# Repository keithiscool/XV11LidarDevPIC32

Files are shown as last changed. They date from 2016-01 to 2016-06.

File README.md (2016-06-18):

This project uses the XV11 Lidar from a Neato Vacuum Cleaner to track a robot in an 4meter x 8meter arena
The object tracking uses the robot reflectance in order to only track reflective surfaces and objects that are far away from the walls
The MPLabX project "lidarpic_FloatingPoint.X" in the software folder uses a PIC32MX575F512H-80I/PT (ordered from Digikey) micro-controller running at 80MHz
The hardware PCB used is the "FAB_xv11_lidar_dev_2016_01_24" EagleCAD file located in the Hardware folder.

Note: you need to use an FTDI chip to debug the project.
Look at the 6 pin (looks like Arduino ISP header. 
FTDI board rx pin goes to Uart 6 on pic32
Ground goes to ground on the same 6 pin header

Next, run a serial debugger program on your pc like realterm, teraterm, arduino to debug the UART line from the pic32
Also double check the lidar is connected.
The headers are loose on the pic32 header for UART4. hook lidar brown/yellow wire (Lidar tx) to the pic32 (UART4RX). Hook up the lidar power and ground.

The MOSFET and Diode that are being pulsed use the circuit in the included PDF: "Lidar Development Using PIC32MX Microcontroller"
Next hook up the motor power to the +5V pin next to the air wired mosfet.
YOU WILL HAVE TO REPROGRAM THE pic32 when you first power it on with the pickit3 programmer. The pic32 will stop spinning the lidar until the pic32 is re-programmed.

I recommend you make the following changes for the Wii Camera/Lidar board.
1) Add 3.3V pin for Wii Cameras
2) Choose a pic32MX with more independent timers (1 or 2 more 16 bit timers) - the pic32 only has 4 independent timers
3) Switching buck converters (switching down power converters) to help with battery efficiency
4) Add more output capacitance for voltage LDO regulators if you do not use a switching regulator
5) Beef up 3.3V trace on board
6) Place 5V power for lidar next to lidar input pins (place +5V next to UA4RX)

7) Choose an isolated mosfet driver (the one we used was not isolated (grounds were tied – too much noise)
8) Integrate a large mosfet onto the board and use the mosfet driver with it with the attached circuit (see attachment)
9) Choosing locking connectors OR solder all wires to board
10) Move programming header closer to pic32 and avoid meandering traces under & over board

Recommendations:
11) Add a non-ultrasonic distance meter to help with backing up the robot
12) Get ultra-reflective surfaces for TRACEE to help with LIDAR (Aluminum reflectance varied too much from 70 to 130 quality)
13) Use a Gimbal/gyro on the Lidar to help keep it level with arena sand
14) Lower Lidar to sit in the arena like I left it (this will prevent false positives from the judges
15) Look into dust tolerance methods for Lidar (static electricity/magnetism/sound vibrations/solenoid)

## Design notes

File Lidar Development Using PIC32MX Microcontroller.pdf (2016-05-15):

## Neato XV11 Lidar Development Using PIC32MX Microcontroller

Keith Martin
NASA Robotics Mining Team

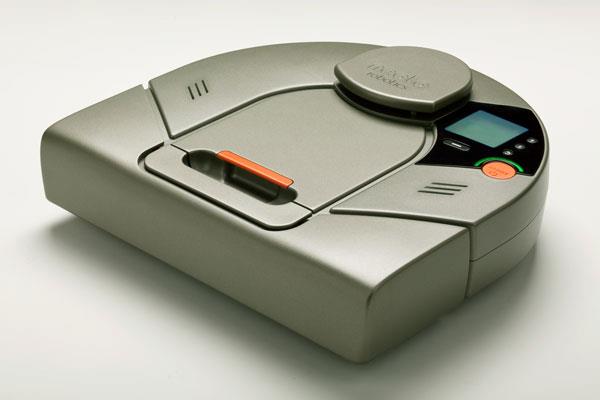
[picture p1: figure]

## CRC

- A Cyclical Redundancy Check is a method to verify that the received data is valid.
- The CRC used here is two bytes added on the end of the data message. The two bytes are compared with the received first bytes in green below.
<start> <index> <speed_L> <speed_H> [Data 0] [Data 1] [Data 2] [Data 3] <checksum_L> <checksum_H>

Parsed Output from Software After CRC

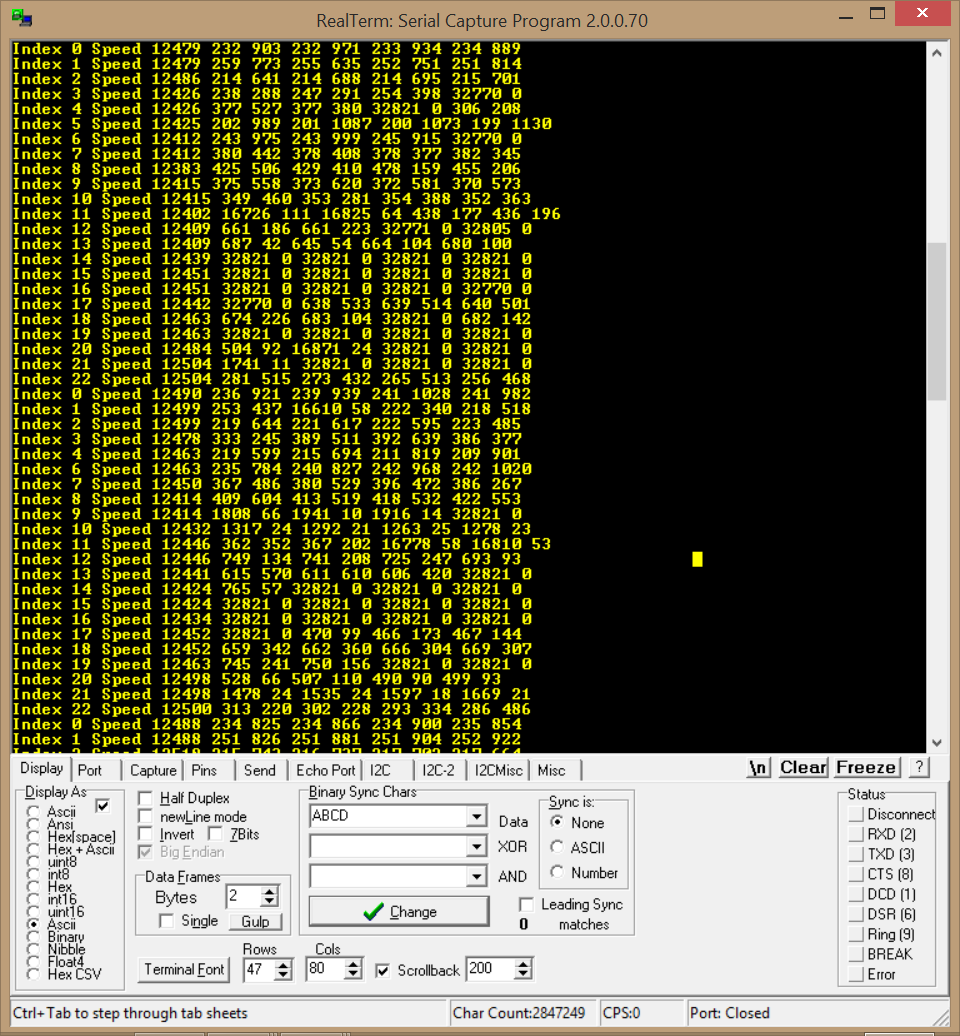
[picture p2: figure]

## How to Hookup the Lidar Hardware

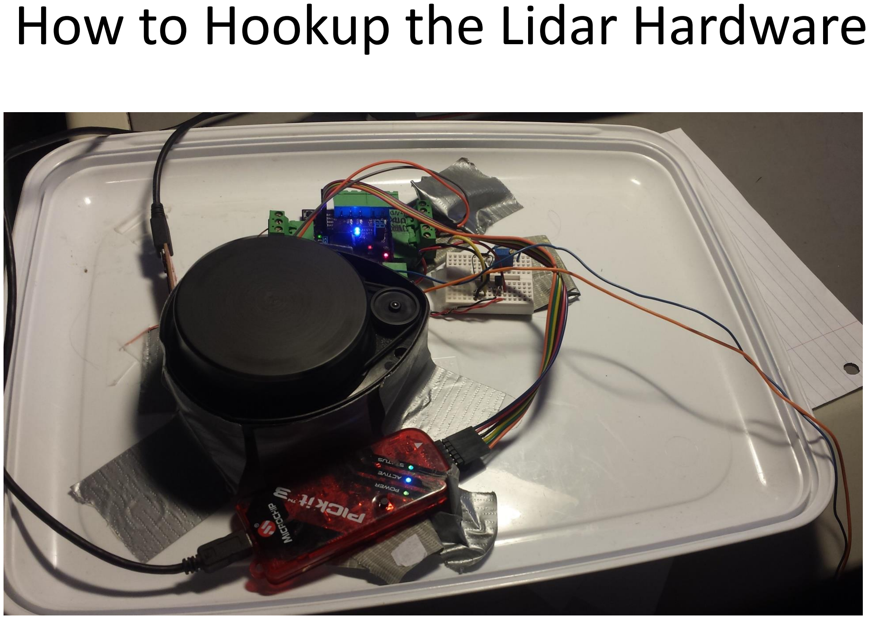
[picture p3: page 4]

## Fixed Point Math for Lookup Table

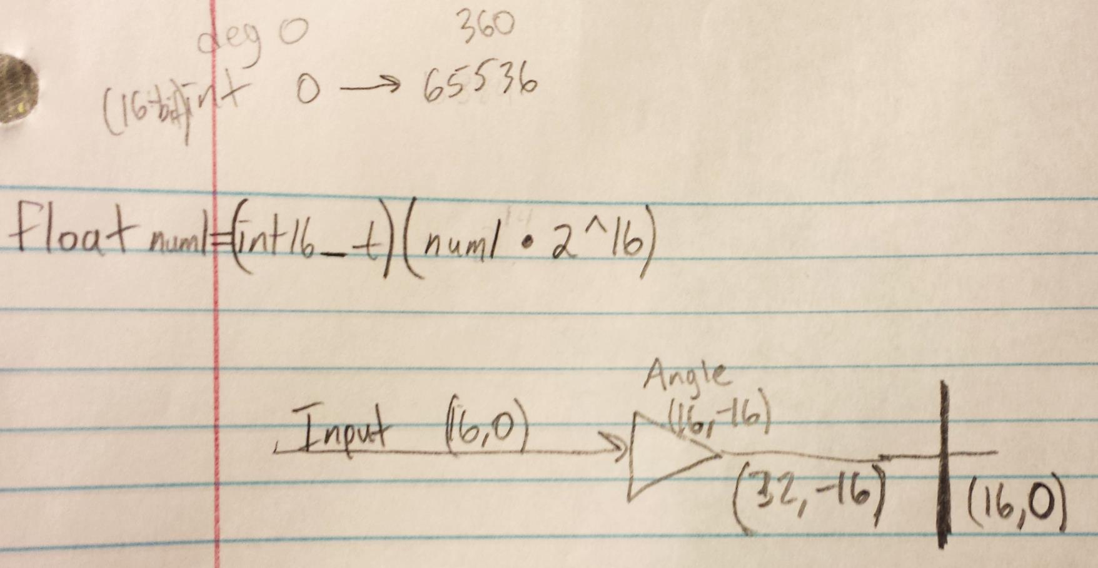
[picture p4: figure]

## Controlling the DC Motor

- Transistor base is connected to microcontroller
– Microcontroller sends PWM to transistor base – Diode prevents coils in
motor from inducing a large
voltage spike.

V = L

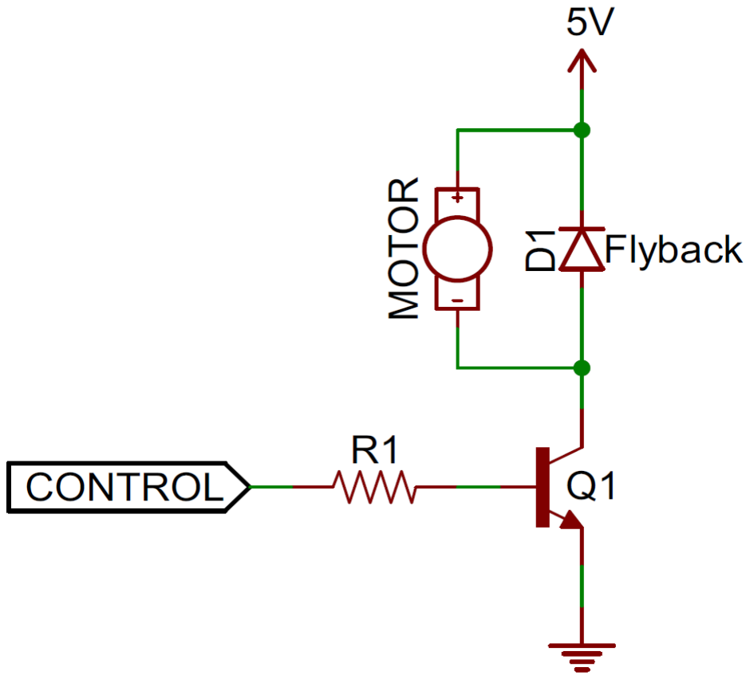
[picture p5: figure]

di
dt

## Site Info and Repository

https://xv11hacking.wikispaces.com/LIDAR+Senshttps://github.com/keithiscool/XV11LidarDevelopment PIC32 (https://github.com/keithiscool/XV11LidarDevelopmentPIC32)

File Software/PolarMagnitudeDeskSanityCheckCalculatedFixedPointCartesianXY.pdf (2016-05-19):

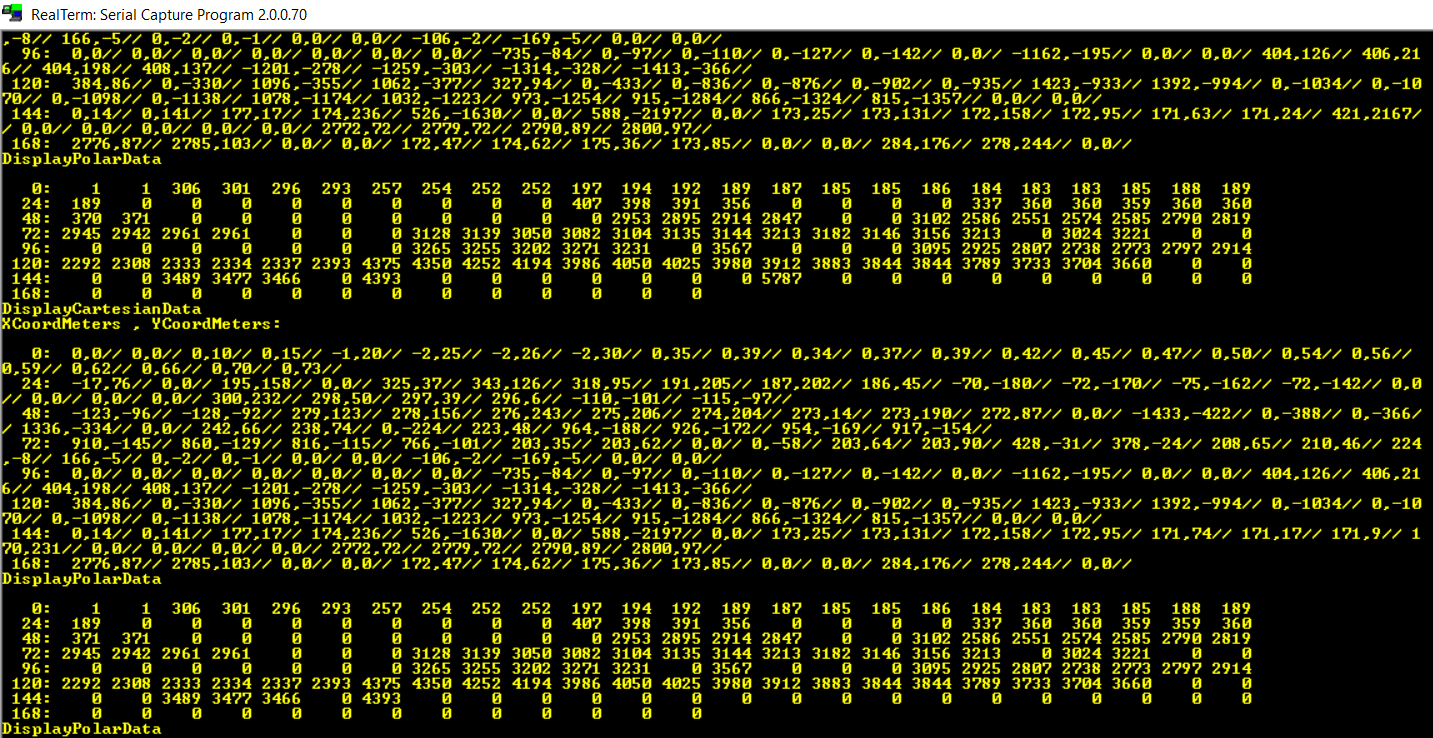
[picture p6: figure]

Lidar Polar Magnitudes on desk sanity check with the Calculated Fixed Point Cartesian X,Y coordinates

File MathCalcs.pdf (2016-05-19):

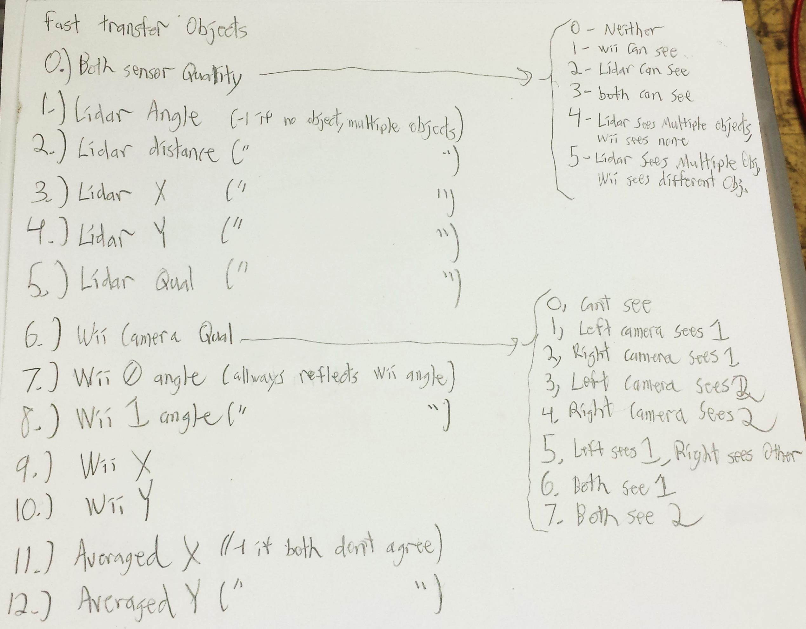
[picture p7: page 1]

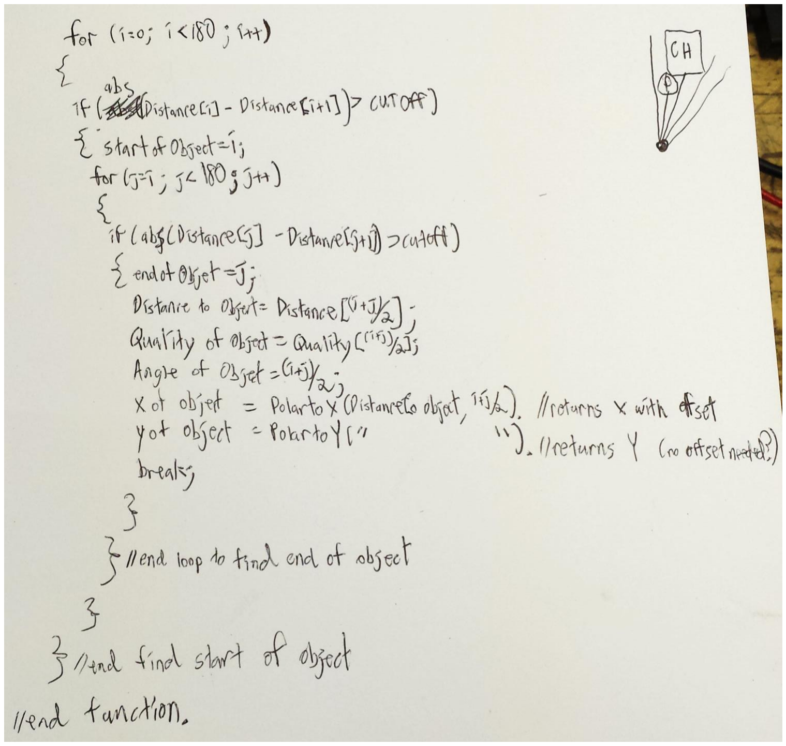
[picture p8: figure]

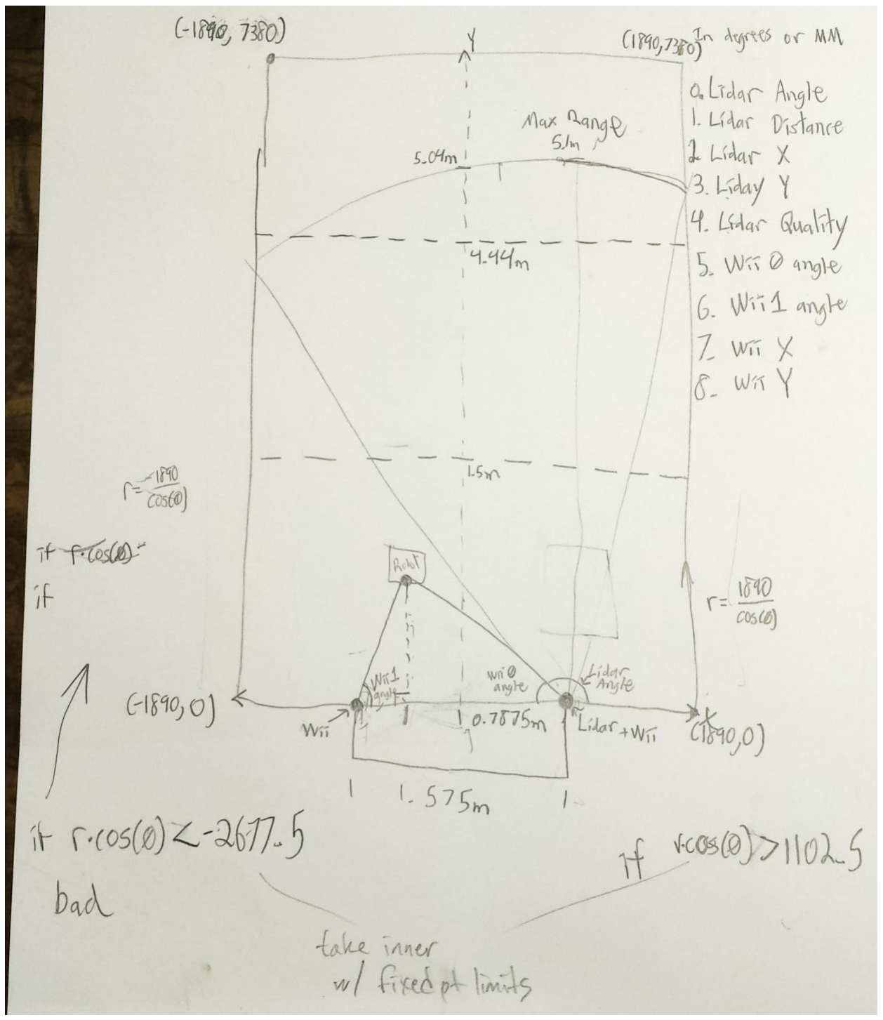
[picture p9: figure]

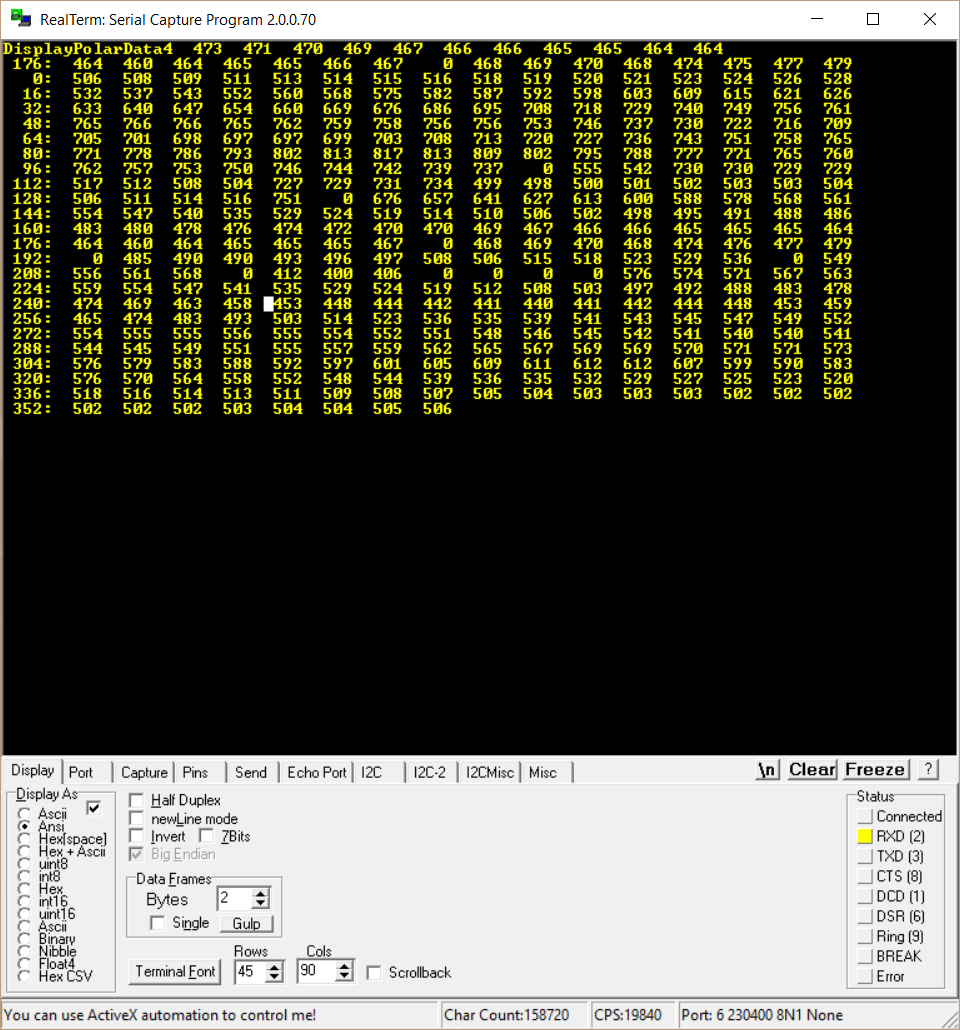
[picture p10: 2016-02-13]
Software/Data_Logging/XV11Lidar_Distances_Polar.png

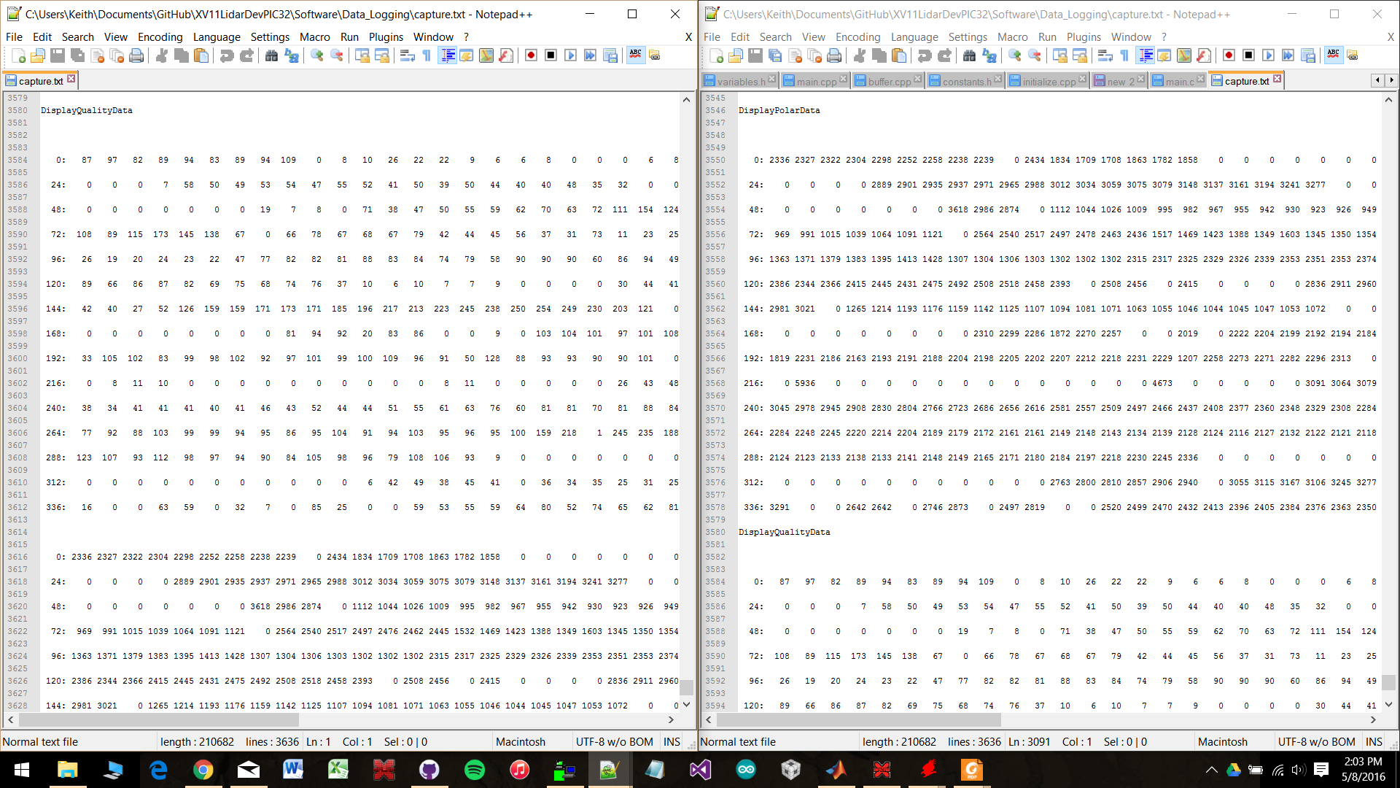
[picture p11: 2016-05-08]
Software/Data_Logging/QualityCheck.png

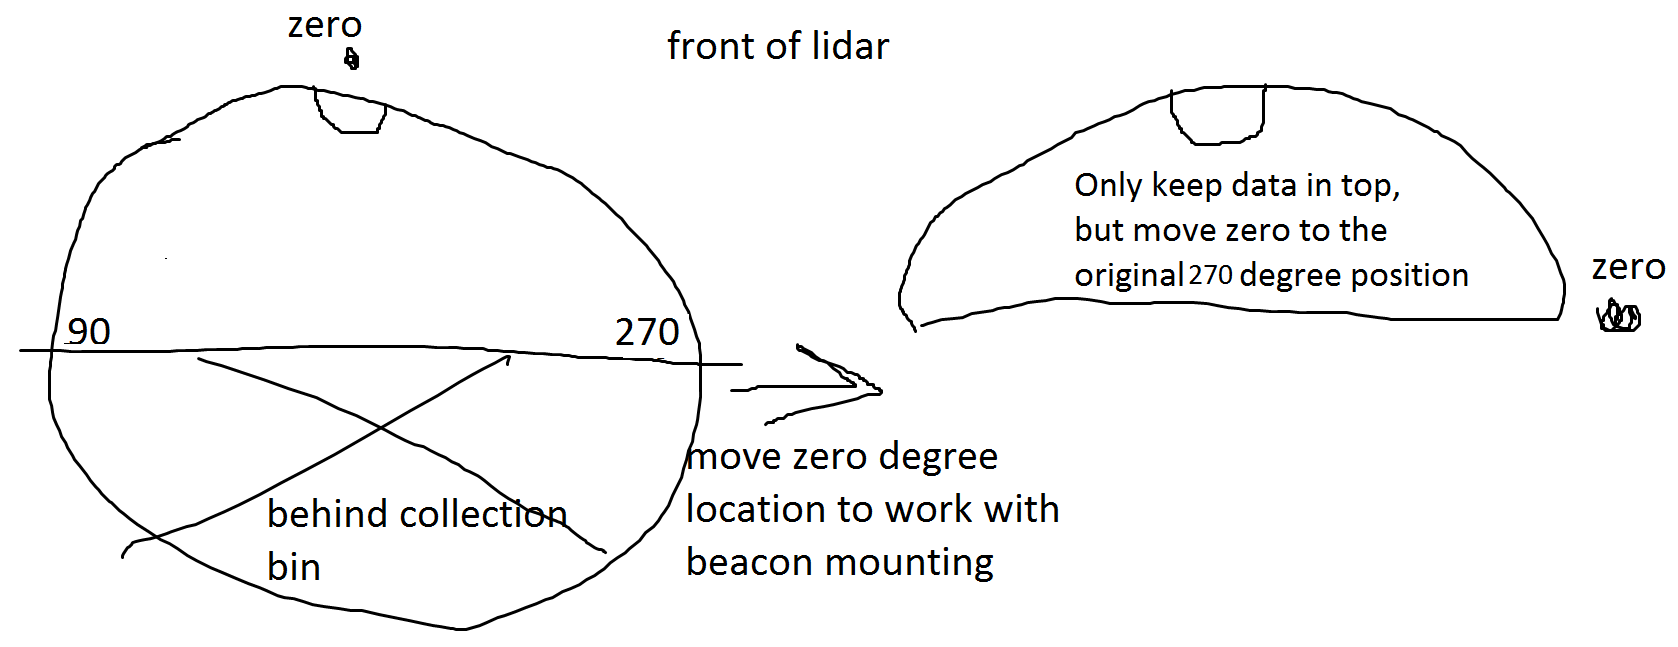
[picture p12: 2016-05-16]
Software/ReOrientLidarForBeaconAgainstCollectionWall.png

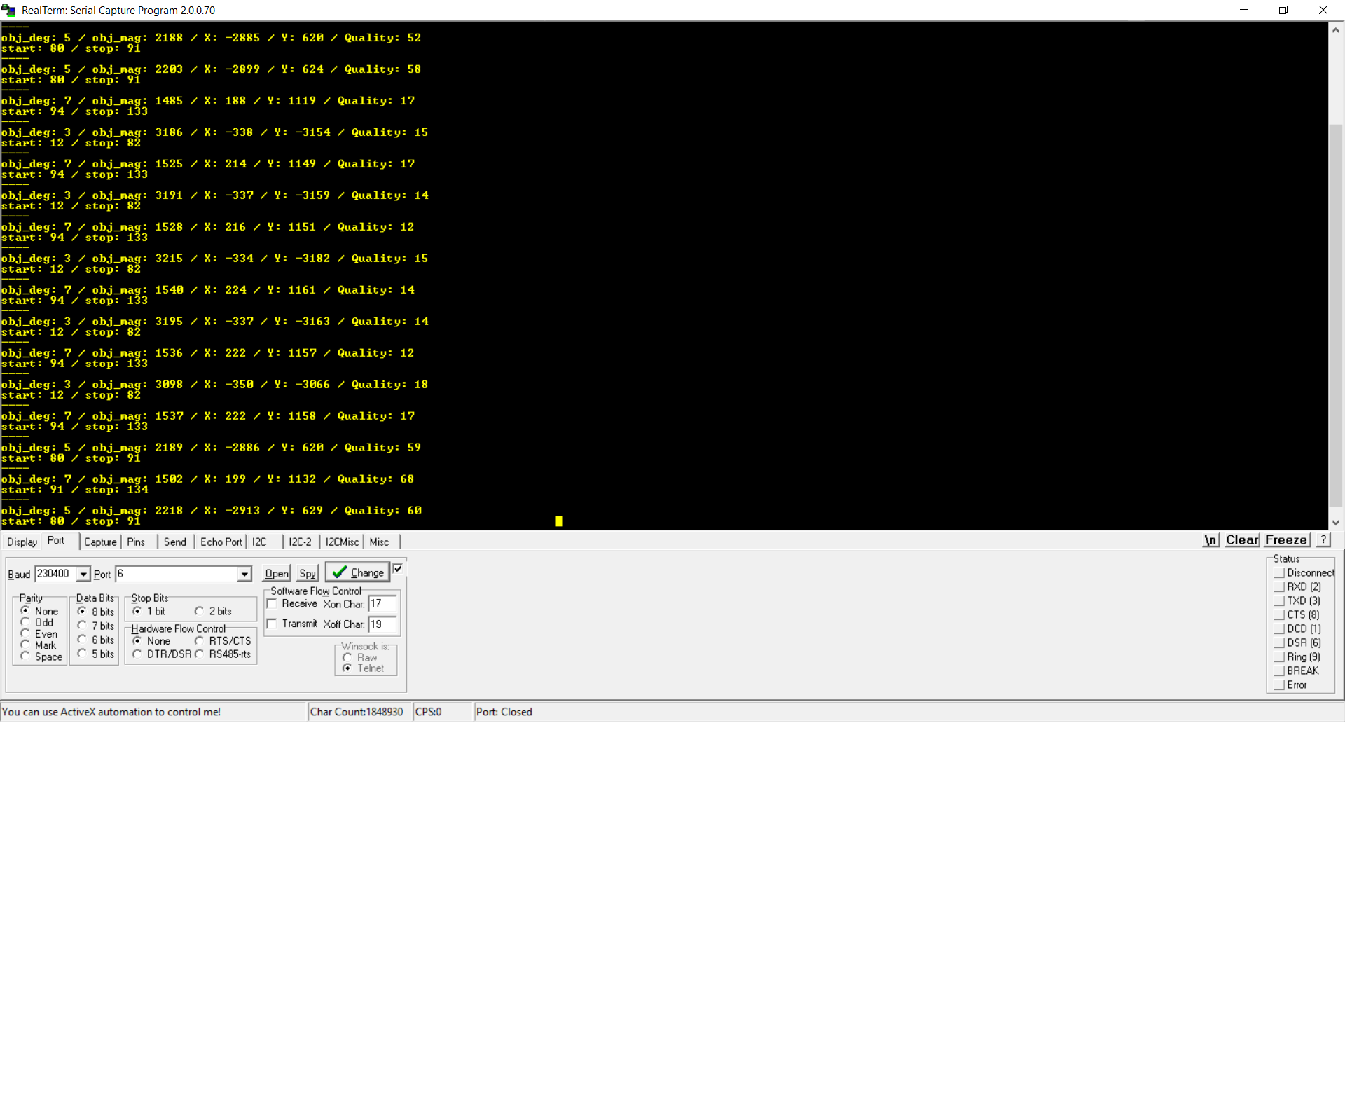
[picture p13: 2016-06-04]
Software/Data_Logging/WORKING_ObjectTrackingSample.png

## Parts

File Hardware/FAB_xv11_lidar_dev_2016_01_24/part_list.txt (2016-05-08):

Partlist

Exported from xv11_lidar_controller.brd at 4/28/2016 9:19:55 PM

EAGLE Version 6.5.0 Copyright (c) 1988-2013 CadSoft

Assembly variant: 

Part               Value                          Package                           Library                        Position (mil)        Orientation

3.3V_REG           BA33DD0WHFP-TR                 HRP5                              NASA_LIB                       (1240 2170)           MR0
ANALOG             M05LOCK                        1X05_LOCK                         SparkFun-Connectors            (1832.5 1012.5)       R90
C3                 1000pF Ceramic 50V             0805                              SparkFun-Capacitors            (1367.5 395)          MR90
C4                 0.1uF ceramic 16V              C0805K                            adafruit                       (755 1865)            MR270
C5                 100uf Tantalum 16v             EIA3216                           SparkFun-Capacitors            (555 1860)            MR90
C7                 10uF ceramic 16V               C0805K                            adafruit                       (672.5 1865)          MR270
C9                 10uf Ceramic 16v               0805                              SparkFun-Capacitors            (397.5 2200)          MR90
C12                0.1uF Ceramic                  0805                              SparkFun-Capacitors            (770 1410)            MR0
C13                0.1uF Ceramic                  0805                              SparkFun-Capacitors            (662.5 1305)          MR90
C14                0.1uF Ceramic                  0805                              SparkFun-Capacitors            (862.5 1307.5)        MR90
C15                0.1uF Ceramic                  0805                              SparkFun-Capacitors            (862.5 1190)          MR270
C16                0.1uF Ceramic                  0805                              SparkFun-Capacitors            (935 1600)            R0
C17                0.1uF Ceramic                  0805                              SparkFun-Capacitors            (447.5 1392.5)        R90
C18                0.1uF Ceramic                  0805                              SparkFun-Capacitors            (337.5 1147.5)        R90
C19                .1uF ceramic 50v               0805                              SparkFun-Capacitors            (1610 877.5)          MR0
C20                10uF Ceramic                   0805                              SparkFun-Capacitors            (712.5 1185)          MR270
C21                0.1uF Ceramic                  0805                              SparkFun-Capacitors            (795 1185)            MR270
C28                10uF ceramic 16V               0805                              SparkFun-Capacitors            (980 2130)            MR90
D1                 ES2AA-13-F                     SMA-DIODE                         SparkFun-DiscreteSemi          (405 1845)            MR90
D2                 ES2AA-13-F                     SMA-DIODE                         SparkFun-DiscreteSemi          (1270 272.5)          MR0
ECS-240-20-33-TR1  ECS-240-20-33-TR_24mHz_Digikey ECX-32                            Crystal ECS                    (320 1302.5)          R180
F1                 1AmpFuse_C1S 2                 R1206                             adafruit                       (1085 330)            MR90
F4                 4AmpFuse_C1S 2                 R1206                             adafruit                       (280 2570)            MR90
I2C1               M03LOCK                        1X03_LOCK                         SparkFun-Connectors            (947.5 2710)          R0
I2C2               M03LOCK                        1X03_LOCK                         SparkFun-Connectors            (595 2702.5)          R0
JP1                                               1X05_LOCK                         SparkFun-Connectors            (110 695)             R270
JP2                                               1X05_LOCK                         SparkFun-Connectors            (665 95)              R0
JP3                                               1X05_LOCK                         SparkFun-Connectors            (115 90)              R0
LED0               Blue                           CHIP-LED0805                      adafruit                       (1797.5 1972.5)       R90
LED1               Blue                           CHIP-LED0805                      adafruit                       (1797.5 2045)         R90
LED3               Blue                           CHIP-LED0805                      adafruit                       (1797.5 2112.5)       R90
LED4               Blue                           CHIP-LED0805                      adafruit                       (1795 2180)           R90
LED5               Blue                           CHIP-LED0805                      adafruit                       (1795 2247.5)         R90
LED6               Blue                           CHIP-LED0805                      adafruit                       (1787.5 1735)         R90
LED7               Blue                           CHIP-LED0805                      adafruit                       (1787.5 1840)         R90
LIDAR                                             1X04_LOCK                         SparkFun-Connectors            (1497.5 97.5)         R0
LIDAR_MOTOR_OUTPUT M02LOCK                        1X02_LOCK                         SparkFun-Connectors            (1220 97.5)           R0
MOTORA             Yellow                         CHIP-LED0805                      adafruit                       (810 455)             R180
PIC32              PIC32MX575F512H-80I/PT         QFP50P1200X1200X120-64N           Microchip_By_element14_Batch_1 (765 1285)            R180
PIC_PROG1          Prog                           1X05_LOCK_LONGPADS                SparkFun-Connectors            (1712.5 705)          R180
POWER              Green                          CHIP-LED0805                      adafruit                       (440 2720)            R270
Q1                 MOSFET-NCHANNELBSS138          SOT23                             SparkFun-DiscreteSemi          (990 1878)            MR0
Q2                 MOSFET-NCHANNELBSS138          SOT23                             SparkFun-DiscreteSemi          (1453 1817)           MR0
R1                 10 5%                          R0805                             adafruit                       (1085 1605)           R0
R2                 2.2k                           R0805                             adafruit                       (1285 1940)           R270
R3                 10k 5%                         R0805                             adafruit                       (1499 2358)           MR270
R4                 100 5%                         M0805                             adafruit                       (772.5 327.5)         R0
R5                 100 5%                         R0805                             adafruit                       (951 1734)            MR0
R6                 2.2k                           R0805                             adafruit                       (1787.5 1617.5)       MR0
R7                 100 5%                         R0805                             adafruit                       (1170 1000)           R90
R8                 2.2k                           M0805                             adafruit                       (640 495)             R180
R9                 10k 5%                         R0805                             adafruit                       (1460 955)            R270
R10                2.2k                           R0805                             adafruit                       (1365 1940)           R270
R11                2.2k                           R0805                             adafruit                       (1205 1940)           R270
R12                2.2k                           R0805                             adafruit                       (1125 1940)           R270
R13                2.2k                           R0805                             adafruit                       (1045 1940)           R270
R14                2.2k                           R0805                             adafruit                       (1787.5 1732.5)       MR0
R15                2.2k                           R0805                             adafruit                       (1787.5 1837.5)       MR0
R16                2.2k 5%                        R0805                             adafruit                       (869 1866)            MR270
R17                2.2k 5%                        R0805                             adafruit                       (1343 1713)           MR270
R18                2.2k 5%                        M0805                             adafruit                       (1810 262.5)          R0
R19                2.2k 5%                        M0805                             adafruit                       (1455 267.5)          R180
R20                100 5%                         R0805                             adafruit                       (1700 1285)           MR180
R21                100 5%                         R0805                             adafruit                       (1468 1669)           MR0
R22                10k 5%                         R0805                             adafruit                       (1712 2366)           MR270
R23                100 5%                         R0805                             adafruit                       (1700 1205)           MR180
R24                100 5%                         R0805                             adafruit                       (1700 1125)           MR180
R25                100 5%                         R0805                             adafruit                       (1700 1045)           MR180
R26                100 5%                         R0805                             adafruit                       (1700 1365)           MR180
R39                2.2k                           R0805                             adafruit                       (397.5 2360)          MR90
S1                                                TACTILE-SWITCH-SMD                SparkFun-Electromechanical     (815 705)             R180
SERVO1                                            1X03                              SparkFun-Connectors            (1492.5 2712.5)       R180
SERVO2                                            1X03                              SparkFun-Connectors            (1840 2715)           R180
TOUCHSCREEN                                       2X3-NS                            SparkFun-Connectors            (1610 432.5)          R0
U$1                ULN2003                        SOIC16_3.9WIDE                    NASA_LIB                       (810 485)             MR180
U$2                ULN2003                        SOIC16_3.9WIDE                    NASA_LIB                       (355 540)             MR270
U$3                JUMPER-PAD-2-NC_BY_TRACE       PAD-JUMPER-2-NC_BY_TRACE_YES_SILK SparkFun-Passives              (287.5 1562.5)        R0
U$4                JUMPER-PAD-2-NC_BY_TRACE       PAD-JUMPER-2-NC_BY_TRACE_YES_SILK SparkFun-Passives              (287.5 1504)          R0
U$5                JUMPER-PAD-2-NC_BY_TRACE       PAD-JUMPER-2-NC_BY_TRACE_YES_SILK SparkFun-Passives              (360.5 1854.5)        R90
U$6                JUMPER-PAD-2-NC_BY_TRACE       PAD-JUMPER-2-NC_BY_TRACE_YES_SILK SparkFun-Passives              (301.5 1855)          R90
U1                 BA50DD0WHFP-TR                 HRP5                              NASA_LIB                       (690 2170)            MR0
U2                 LANTRONIX_A/B                  LANA/BTH                          NASA_LIB                       (885 1745)            R0
U3                 MIC4427YM                      SO-08                             transistor-power               (1167.5 355)          R0
UARTRX4            Green                          CHIP-LED0805                      adafruit                       (1695 232.5)          R180
UARTTX4            Red                            CHIP-LED0805                      adafruit                       (1592.5 232.5)        R180
VIN                M02LOCK                        1X02_LOCK                         SparkFun-Connectors            (165 2750)            R0
WLAN               Blue                           CHIP-LED0805                      adafruit                       (1787.5 1617.5)       R90

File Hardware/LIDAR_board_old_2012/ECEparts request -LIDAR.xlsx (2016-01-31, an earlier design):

 |  |  | ECE PARTS REQUEST ORDERING FORM
 |  | Student Name: | Richard Johnson | Email:
 |  | Project Name: | NASA Lunabot |  | Date Submitted:
 | Faculty Advisor Approval: |  |  |  | Date Ordered:
 |  | Email the completed form to: | glewis@uakron.edu |  | Ordered By:
 |  |  |  |  |  |  | Unit | Total
Qty. | Refdes | Part Num. | Description | Suggested Vendor | Vendor Part Num. | Catalog #/Page #/Website | Cost | Cost
4 |  | 440054-4 | CONN HEADER 4POS 2MM VERT | Digikey | A100036-ND | http://search.digikey.com/us/en/products/440054-4/A100036-ND/2077941?wt.mc_id=Dxn_US_US2010_Catlink | 0.28 | 1.12
4 |  | 440054-2 | CONN HEADER 2POS 2MM VERT | Digikey | A100034-ND | http://search.digikey.com/us/en/products/440054-2/A100034-ND/2077939?wt.mc_id=Dxn_US_US2010_Catlink | 0.11 | 0.44
4 |  | ATMEGA644P-20AU | IC MCU AVR 64K FLASH 44-TQFP | Digikey | ATMEGA644P-20AU-ND | http://search.digikey.com/us/en/products/ATMEGA644P-20AU/ATMEGA644P-20AU-ND/1245864 | 8.08 | 32.32
8 |  | T491A106M016AT | CAP TANT 10UF 16V | Digikey | 399-3687-1-ND | http://search.digikey.com/us/en/products/T491A106M016AT/399-3687-1-ND/819012 | 0.54 | 4.32
4 |  | T491C106K025AT | CAP TANT 10UF 25V | Digikey | 399-3734-1-ND | http://search.digikey.com/us/en/products/T491C106K025AT/399-3734-1-ND/819059 | 0.79 | 3.16
4 |  | 0ZCA0020FF2E | PTC RESTTBLE 0.20A 30V | Digikey | 507-1478-1-ND | http://search.digikey.com/us/en/products/0ZCA0020FF2E/507-1478-1-ND/2165307 | 0.28 | 1.12
20 |  | GRM21BR71E104KA01L | CAP CER 0.1UF 25V | Digikey | 490-1673-1-ND | http://search.digikey.com/us/en/products/GRM21BR71E104KA01L/490-1673-1-ND/587412 | 0.188 | 3.76
12 |  | ERJ-6GEYJ102V | RES 1.0K OHM 1/8W | Digikey | P1.0KACT-ND | http://search.digikey.com/us/en/products/ERJ-6GEYJ102V/P1.0KACT-ND/42833 | 0.04 | 0.48
4 |  | ERJ-6GEYJ103V | RES 10K OHM 1/8W | Digikey | P10KACT-ND | http://search.digikey.com/us/en/products/ERJ-6GEYJ103V/P10KACT-ND/43118 | 0.04 | 0.16
4 |  | LTST-C191KGKT | LED GREEN CLEAR THIN 0603 SMD | Digikey | 160-1446-1-ND | http://search.digikey.com/us/en/products/LTST-C191KGKT/160-1446-1-ND/386834 | 0.45 | 1.80
4 |  | LTST-C190KRKT | LED SUPER RED CLEAR 0603 | Digikey | 160-1436-1-ND | http://search.digikey.com/us/en/products/LTST-C190KRKT/160-1436-1-ND/386816 | 0.41 | 1.64
4 |  | LTST-C190KYKT | LED AMBER YELLOW CLEAR 0603 | Digikey | 160-1438-1-ND | http://search.digikey.com/us/en/products/LTST-C190KYKT/160-1438-1-ND/386820 | 0.46 | 1.84
4 |  | MAX485CSA+ | IC TXRX RS485/RS422 LOWPWR 8SOIC | Digikey | MAX485CSA+-ND | http://search.digikey.com/us/en/products/MAX485CSA%2B/MAX485CSA%2B-ND/948027 | 2.89 | 11.56
4 |  | EVQ-PF008K | SWITCH TACTILE SPST-NO | Digikey | P10880S-ND | http://search.digikey.com/scripts/DkSearch/dksus.dll?WT.z_header=search_go&lang=en&site=us&x=0&y=0 | 0.29 | 1.16
20 |  | 1547E | STANDOFF RND 4-40THR BR 1.00"L | Digikey | 1547EK-ND | http://search.digikey.com/us/en/products/1547E/1547EK-ND/303619 | 1.197 | 23.94
1 |  | uLCD43 | Serial TFT LCD 4.3" with Touchscreen | Sparkfun | LCD-11075 | http://www.sparkfun.com/products/11075 | 139.95 | 139.95
4 |  | BlinkM MaxM | I2C Controlled RGB LED | Sparkfun | COM-09000 | http://www.sparkfun.com/products/9000 | 24.95 | 99.80
1 |  | N/A | Metal Pushbutton with Red LED Ring -NO | Adafruit | 559 | https://www.adafruit.com/products/559 | 5.95 | 5.95
 |  |  |  |  |  |  |  | 0.00
 |  |  |  |  |  |  |  | 0.00
 |  |  |  |  |  |  |  | 0.00
 |  |  |  |  |  |  |  | 0.00
 |  |  |  |  |  |  |  | 0.00
 |  |  |  |  |  |  |  | 0.00
 |  |  |  |  |  |  |  | 0.00
 |  |  |  |  |  |  |  | 0.00
 |  |  |  |  |  |  |  | 0.00
 |  |  |  |  |  |  |  | 0.00
 |  |  |  |  |  |  |  | 0.00
 |  |  |  |  |  |  |  | 0.00
 |  |  |  |  |  |  |  | 0.00
 |  |  |  |  |  |  |  | 0.00
 |  |  |  |  |  |  |  | 0.00
 |  |  |  |  |  |  |  | 0.00
 |  |  |  |  |  |  |  | 0.00
 |  |  |  |  |  |  |  | 0.00
 |  |  |  |  |  |  |  | 0.00
 |  |  |  |  |  |  |  | 0.00
 |  |  |  |  |  |  |  | 0.00
 |  |  |  |  |  |  |  | 0.00
 |  |  |  |  |  |  | Total | $334.52

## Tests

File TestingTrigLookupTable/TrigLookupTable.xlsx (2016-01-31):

 | Fixed Point Math: |  | http://stackoverflow.com/questions/187713/converting-floating-point-to-fixed-point
 | DO NOT EXCEED: |  | 4294967296 |  | 65536 | Scaled to 16 bits | Output in (16,-16) Format == 0integer bits,16fraction bits
 | Scaler: | 1000
Degrees | SinVal(float) | round(SinVal(float)*Scaler) |  | Scaled Int Value = float*2^16 |  | Rounded Int Value
0 | 0 | 0 |  | 0 |  | 0
1 | 0.01745240644 | 17 |  | 1143.760908 |  | 1144
2 | 0.0348994967 | 35 |  | 2287.173416 |  | 2287
3 | 0.05233595624 | 52 |  | 3429.889228 |  | 3430
4 | 0.06975647374 | 70 |  | 4571.560263 |  | 4572
5 | 0.08715574275 | 87 |  | 5711.838757 |  | 5712
6 | 0.1045284633 | 105 |  | 6850.377369 |  | 6850
7 | 0.1218693434 | 122 |  | 7986.829289 |  | 7987
8 | 0.139173101 | 139 |  | 9120.848345 |  | 9121
9 | 0.156434465 | 156 |  | 10252.0891 |  | 10252
10 | 0.1736481777 | 174 |  | 11380.20697 |  | 11380
11 | 0.1908089954 | 191 |  | 12504.85832 |  | 12505
12 | 0.2079116908 | 208 |  | 13625.70057 |  | 13626
13 | 0.2249510543 | 225 |  | 14742.3923 |  | 14742
14 | 0.2419218956 | 242 |  | 15854.59335 |  | 15855
15 | 0.2588190451 | 259 |  | 16961.96494 |  | 16962
16 | 0.2756373558 | 276 |  | 18064.16975 |  | 18064
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

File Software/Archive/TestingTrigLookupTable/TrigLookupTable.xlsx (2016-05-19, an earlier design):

 | Fixed Point Math: |  | http://stackoverflow.com/questions/187713/converting-floating-point-to-fixed-point
 | DO NOT EXCEED: | Size of int_32_unsigned: 2147483648 |  |  | 65536 | Scaled to 16 bits | Output in (16,-16) Format == 0integer bits,16fraction bits
 | Scaler: | 1000
Degrees | SinVal(float) | round(SinVal(float)*Scaler) |  | Scaled Int Value = float*2^16 |  | Rounded Int Value
0 | 0 | 0 |  | 0 |  | 0
1 | 0.01745240644 | 17 |  | 1143.760908 |  | 1144
2 | 0.0348994967 | 35 |  | 2287.173416 |  | 2287
3 | 0.05233595624 | 52 |  | 3429.889228 |  | 3430
4 | 0.06975647374 | 70 |  | 4571.560263 |  | 4572
5 | 0.08715574275 | 87 |  | 5711.838757 |  | 5712
6 | 0.1045284633 | 105 |  | 6850.377369 |  | 6850
7 | 0.1218693434 | 122 |  | 7986.829289 |  | 7987
8 | 0.139173101 | 139 |  | 9120.848345 |  | 9121
9 | 0.156434465 | 156 |  | 10252.0891 |  | 10252
10 | 0.1736481777 | 174 |  | 11380.20697 |  | 11380
11 | 0.1908089954 | 191 |  | 12504.85832 |  | 12505
12 | 0.2079116908 | 208 |  | 13625.70057 |  | 13626
13 | 0.2249510543 | 225 |  | 14742.3923 |  | 14742
14 | 0.2419218956 | 242 |  | 15854.59335 |  | 15855
15 | 0.2588190451 | 259 |  | 16961.96494 |  | 16962
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

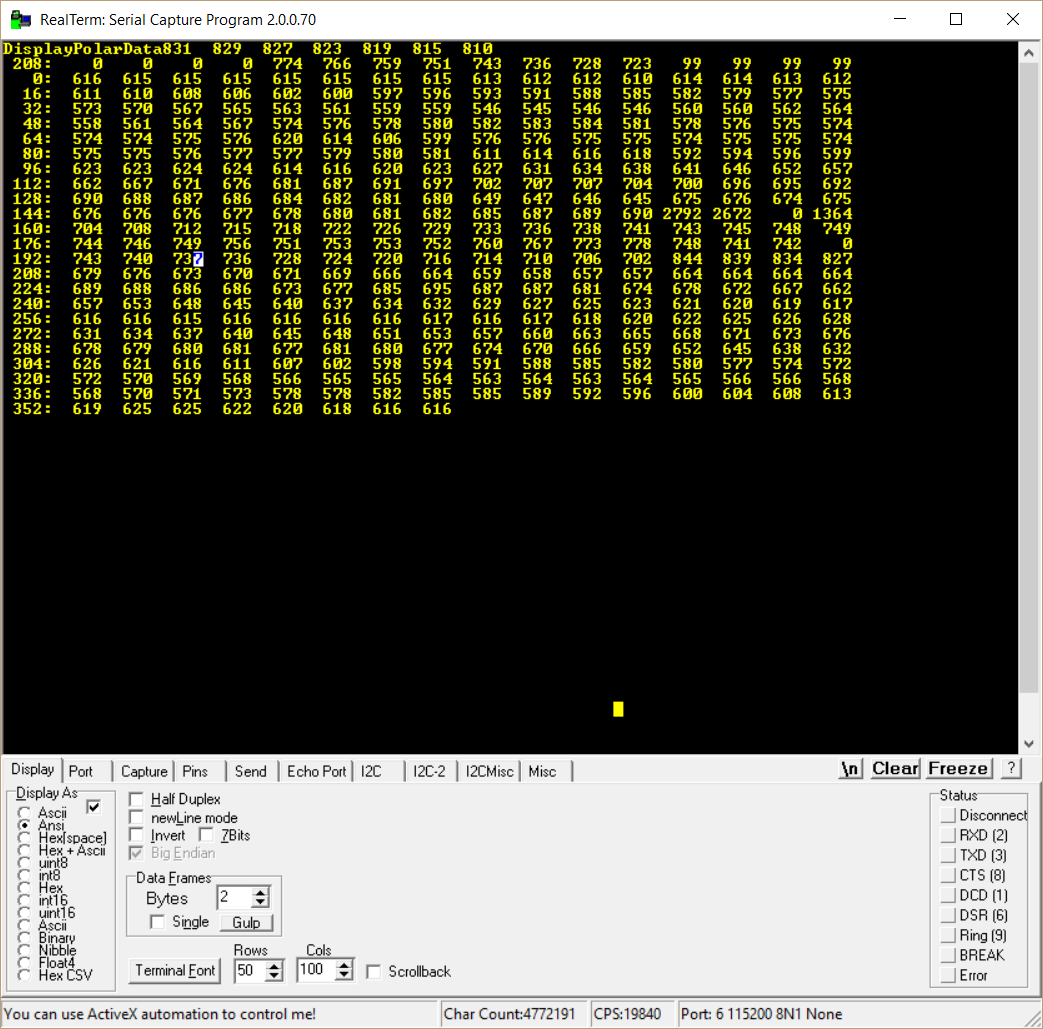
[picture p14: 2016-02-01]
Software/Data_Logging/CircleTestXV11_50cmRadiusCircleWhiteCardboard.png

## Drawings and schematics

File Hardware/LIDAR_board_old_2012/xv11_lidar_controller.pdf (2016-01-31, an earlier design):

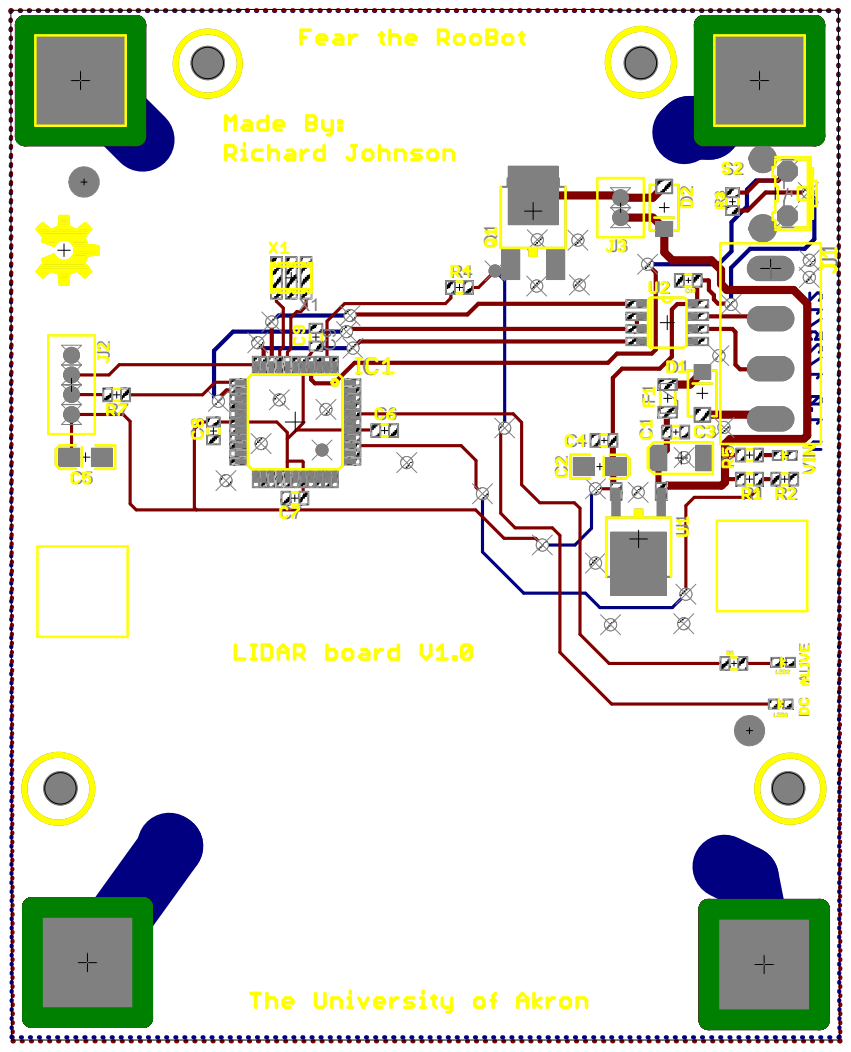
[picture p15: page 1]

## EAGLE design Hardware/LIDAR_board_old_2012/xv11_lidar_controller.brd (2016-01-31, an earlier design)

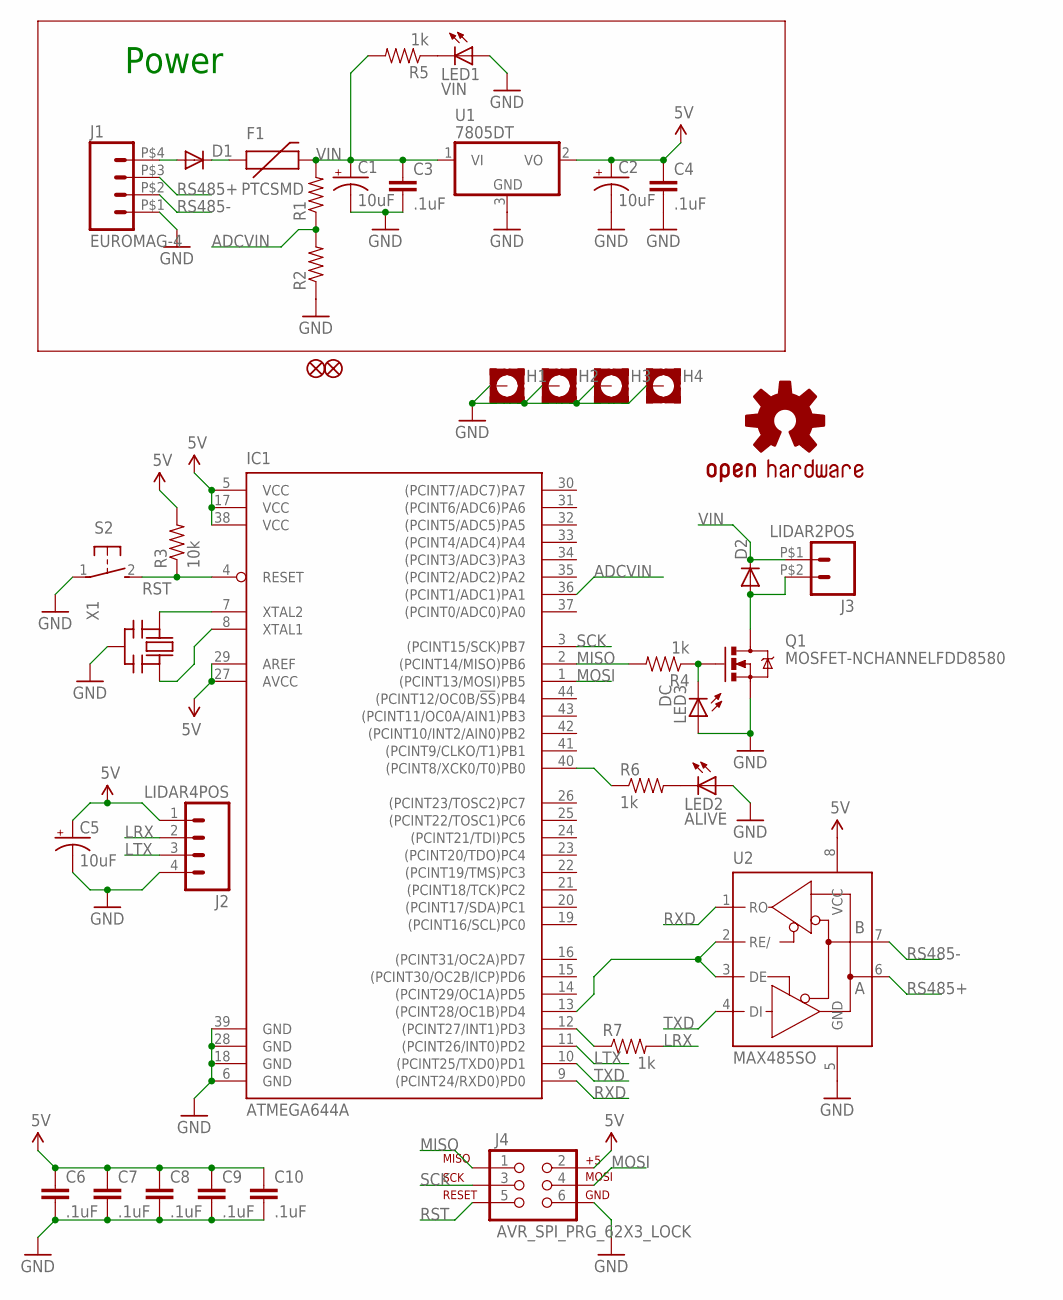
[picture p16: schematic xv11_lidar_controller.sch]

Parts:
C1: 10uF; EIA6032
C2, C5: 10uF; EIA3216-KIT
C3, C4, C6, C7, C8, C9, C10: .1uF; 0805
D1, D2: DIODESMA; SMA-DIODE
F1: PTCSMD; PTC-1206
H1, H2, H3, H4: MOUNT-PAD-SQUARE5.5; 5,5-PAD-SQUARE
IC1: ATMEGA644A; TQFP44
J1: EUROMAG-4; M4
J2: LIDAR4POS; 2MM4POS
J3: LIDAR2POS; 2MM2POS
J4: AVR_SPI_PRG_62X3_LOCK; 2X3_LOCK
JP1, JP2: FIDUCIAL1.5X3; FIDUCIAL-1.5X3
LED1: VIN; LED-0603
LED2: ALIVE; LED-0603
LED3: DC; LED-0603
Q1: MOSFET-NCHANNELFDD8580; DPAK
R1, R2: RESISTOR0805-RES; 0805
R3: 10k; 0805
R4, R5, R6, R7: 1k; 0805
S2: 31-XX; B3F-31XX
U1: 7805DT; TO252
U2: MAX485SO; SO08
U$2: OSHW-LOGOL; OSHW-LOGO-L
X1: CERMOSCILL-AWCSR; AWCSR

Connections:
5V: C2.A (+), C4.1, C5.A (+), C6.1, C7.1, C8.1, C9.1, C10.1, IC1.5 (VCC), IC1.17 (VCC), IC1.27 (AVCC), IC1.29 (AREF), IC1.38 (VCC), J2.1, J4.2, R3.2, U1.2 (VO), U2.8 (VCC)
ADCVIN: IC1.36 ((PCINT1/ADC1)PA1), R1.1, R2.2
GND: C1.P$2 (-), C2.C (-), C3.2, C4.2, C5.C (-), C6.2, C7.2, C8.2, C9.2, C10.2, H1.B5,5, H2.B5,5, H3.B5,5, H4.B5,5, IC1.6 (GND), IC1.18 (GND), IC1.28 (GND), IC1.39 (GND), J1.P$1 (1), J2.4, J4.6, LED1.A, LED2.A, LED3.A, Q1.3 (S), R2.1, S2.1, U1.3 (GND), U2.5 (GND), X1.2 (GND)
LRX: J2.2, R7.2
LTX: IC1.11 ((PCINT26/INT0)PD2), J2.3
MISO: IC1.2 ((PCINT14/MISO)PB6), J4.1, R4.2
MOSI: IC1.1 ((PCINT13/MOSI)PB5), J4.4
unnamed: D1.A, J1.P$4 (4)
unnamed: D1.C, F1.1
unnamed: LED3.C, Q1.1 (G), R4.1
unnamed: LED1.C, R5.1
unnamed: IC1.40 ((PCINT8/XCK0/T0)PB0), R6.1
unnamed: LED2.C, R6.2
unnamed: D2.A, J3.P$2 (2), Q1.4 (D)
unnamed: IC1.13 ((PCINT28/OC1B)PD4), U2.2 (RE/), U2.3 (DE)
unnamed: IC1.12 ((PCINT27/INT1)PD3), R7.1
unnamed: IC1.7 (XTAL2), X1.1 (IN)
unnamed: IC1.8 (XTAL1), X1.3 (OUT)
RS485+: J1.P$3 (3), U2.6 (A)
RS485-: J1.P$2 (2), U2.7 (B)
RST: IC1.4 (RESET), J4.5, R3.1, S2.2 (S)
RXD: IC1.9 ((PCINT24/RXD0)PD0), U2.1 (RO)
SCK: IC1.3 ((PCINT15/SCK)PB7), J4.3
TXD: IC1.10 ((PCINT25/TXD0)PD1), U2.4 (DI)
VIN: C1.P$1 (+), C3.1, D2.C, F1.2, J3.P$1 (1), R1.2, R5.2, U1.1 (VI)

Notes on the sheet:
Power

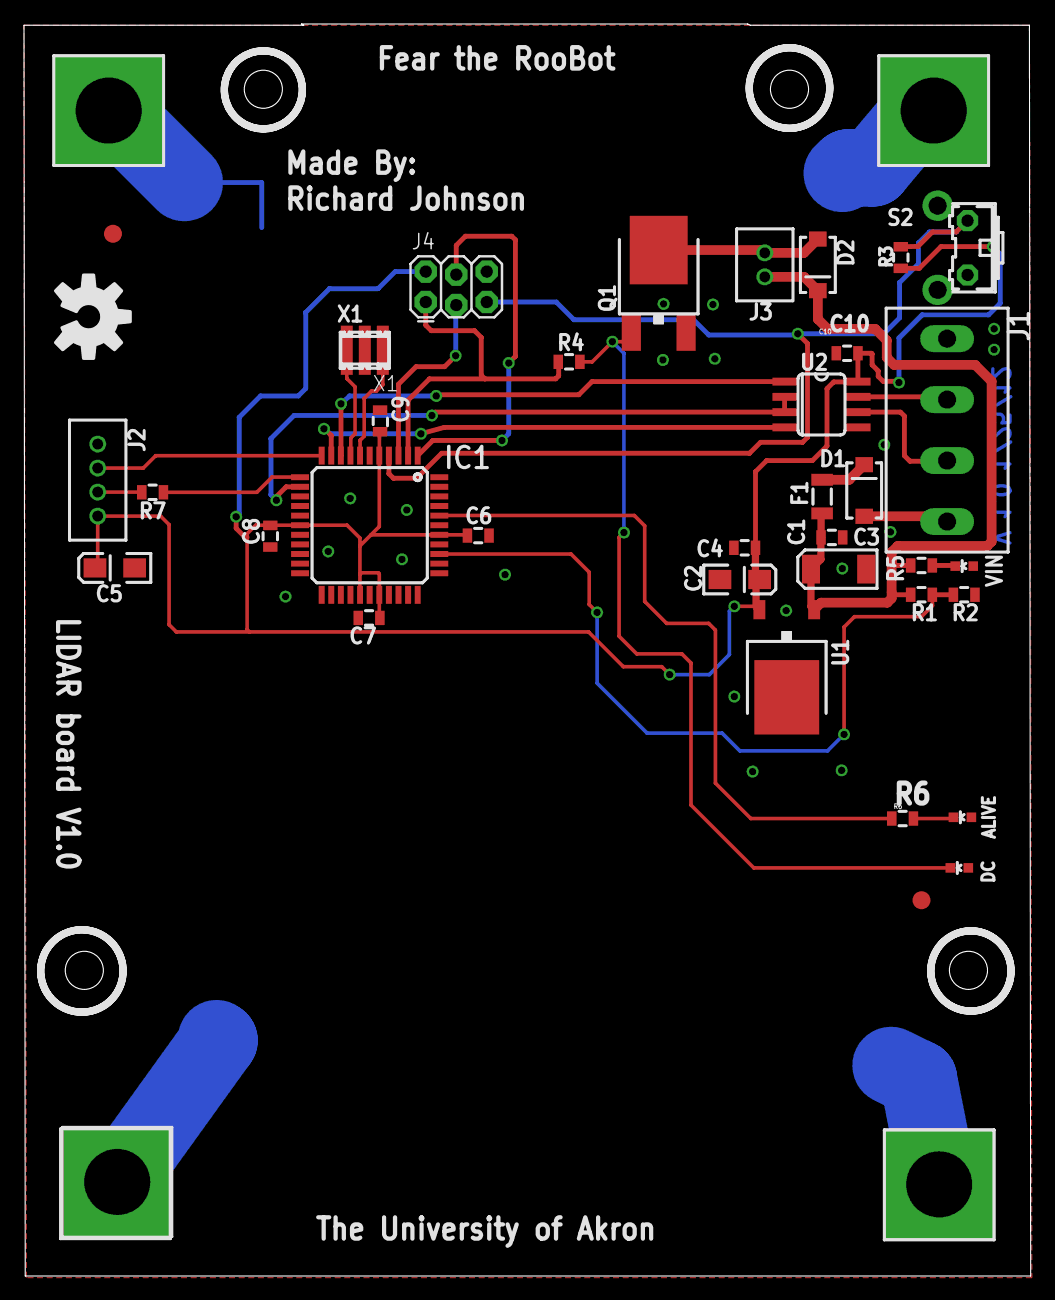
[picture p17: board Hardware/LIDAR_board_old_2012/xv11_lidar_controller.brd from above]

Board: 2 copper layers, 83.9 x 104.3 mm, 40 parts (0 on the bottom side), 25 nets.

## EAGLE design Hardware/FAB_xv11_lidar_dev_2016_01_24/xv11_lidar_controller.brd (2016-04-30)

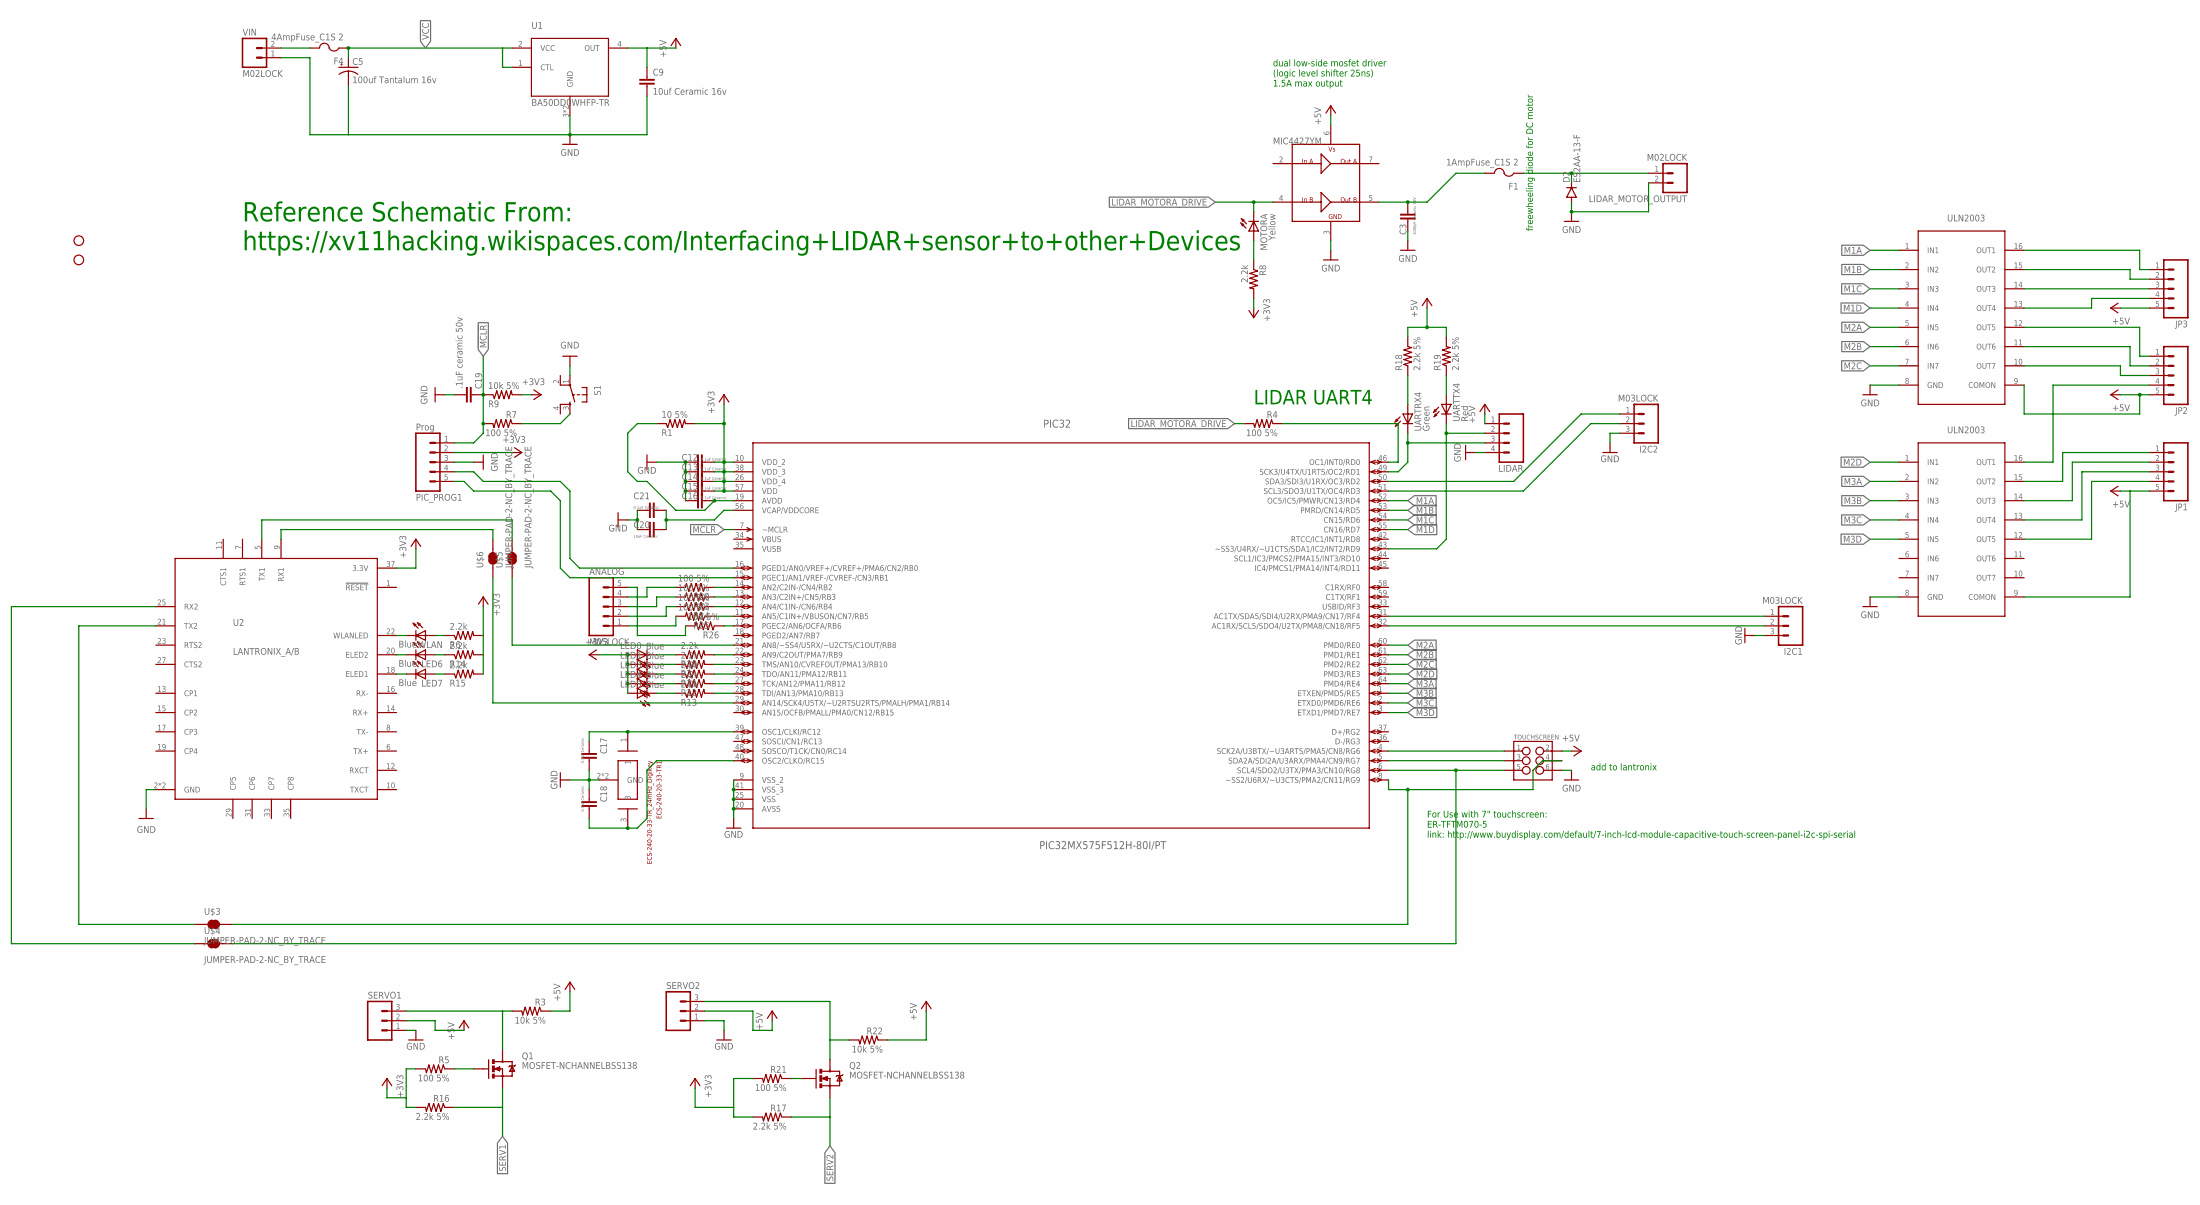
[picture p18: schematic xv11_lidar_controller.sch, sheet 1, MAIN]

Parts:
ANALOG: M05LOCK; 1X05_LOCK
C3: 1000pF Ceramic 50V; 0805
C5: 100uf Tantalum 16v; EIA3216
C9: 10uf Ceramic 16v; 0805
C12, C13, C14, C15, C16, C17, C18, C21: 0.1uF Ceramic; 0805
C19: .1uF ceramic 50v; 0805
C20: 10uF Ceramic; 0805
D2: ES2AA-13-F; SMA-DIODE
ECS-240-20-33-TR1: ECS-240-20-33-TR_24mHz_Digikey; ECX-32
F1: 1AmpFuse_C1S 2; R1206
F4: 4AmpFuse_C1S 2; R1206
I2C1, I2C2: M03LOCK; 1X03_LOCK
JP1, JP2, JP3: M05LOCK; 1X05_LOCK
LED0, LED1, LED3, LED4, LED5, LED6, LED7: Blue; CHIP-LED0805
LIDAR: M04LOCK; 1X04_LOCK
LIDAR_MOTOR_OUTPUT: M02LOCK; 1X02_LOCK
MOTORA: Yellow; CHIP-LED0805
PIC32: PIC32MX575F512H-80I/PT; QFP50P1200X1200X120-64N
PIC_PROG1: Prog; 1X05_LOCK_LONGPADS
Q1, Q2: MOSFET-NCHANNELBSS138; SOT23
R1: 10 5%; R0805
R2, R6, R10, R11, R12, R13, R14, R15: 2.2k; R0805
R3, R9, R22: 10k 5%; R0805
R4: 100 5%; M0805
R5, R7, R20, R21, R23, R24, R25, R26: 100 5%; R0805
R8: 2.2k; M0805
R16, R17: 2.2k 5%; R0805
R18, R19: 2.2k 5%; M0805
S1: TAC_SWITCHSMD; TACTILE-SWITCH-SMD
SERVO1, SERVO2: M03PTH; 1X03
STANDOFF1, STANDOFF2: STAND-OFF
TOUCHSCREEN: M03X2NO_SILK; 2X3-NS
U1: BA50DD0WHFP-TR; HRP5
U2: LANTRONIX_A/B; LANA/BTH
U3: MIC4427YM; SO-08
U$1, U$2: ULN2003; SOIC16_3.9WIDE
U$3, U$4, U$5, U$6: JUMPER-PAD-2-NC_BY_TRACE; PAD-JUMPER-2-NC_BY_TRACE_YES_SILK
UARTRX4: Green; CHIP-LED0805
UARTTX4: Red; CHIP-LED0805
VIN: M02LOCK; 1X02_LOCK
WLAN: Blue; CHIP-LED0805

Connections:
!MCLR: C19.1, PIC32.7 (~MCLR), PIC_PROG1.1, R7.2, R9.1
+3V3: C12.2, C13.2, C14.2, C15.2, LED0.A, LED1.A, LED3.A, LED4.A, LED5.A, PIC32.10 (VDD_2), PIC32.26 (VDD_4), PIC32.38 (VDD_3), PIC32.57 (VDD), PIC_PROG1.2, R1.2, R5.2, R6.2, R8.2, R9.2, R14.2, R15.2, R16.2, R17.2, R21.2, U2.37 (3.3V); also elsewhere on the board
+5V: C9.1, JP1.5, JP2.5, JP3.5, LIDAR.1, R3.1, R18.2, R19.2, R22.1, SERVO1.2, SERVO2.2, TOUCHSCREEN.2, U1.4 (OUT), U3.6 (VS), U$1.9 (COMON), U$2.9 (COMON)
GND: C3.1, C5.C (-), C9.2, C12.1, C13.1, C14.1, C15.1, C16.1, C17.2, C18.1, C19.2, C20.1, C21.1, D2.A, ECS-240-20-33-TR1.2 (GND), ECS-240-20-33-TR1.4 (GND), I2C1.3, I2C2.3, LIDAR.4, LIDAR_MOTOR_OUTPUT.2, PIC32.9 (VSS_2), PIC32.20 (AVSS), PIC32.25 (VSS), PIC32.41 (VSS_3), PIC_PROG1.3, S1.1, SERVO1.1, SERVO2.1, TOUCHSCREEN.6, U1.3 (GND), U1.G (GND), U2.2 (GND), U2.39 (GND), U3.3 (GND), U$1.8 (GND), U$2.8 (GND), VIN.1; also elsewhere on the board
LIDAR_MOTORA_DRIVE: MOTORA.C, R4.2, U3.4 (INB)
LIDAR_MOTOR_OUTPUT: D2.C, F1.1, LIDAR_MOTOR_OUTPUT.1
M1A: PIC32.52 (OC5/IC5/PMWR/CN13/RD4), U$1.1 (IN1)
M1B: PIC32.53 (PMRD/CN14/RD5), U$1.2 (IN2)
M1C: PIC32.54 (CN15/RD6), U$1.3 (IN3)
M1D: PIC32.55 (CN16/RD7), U$1.4 (IN4)
M2A: PIC32.60 (PMD0/RE0), U$1.5 (IN5)
M2B: PIC32.61 (PMD1/RE1), U$1.6 (IN6)
M2C: PIC32.62 (PMD2/RE2), U$1.7 (IN7)
M2D: PIC32.63 (PMD3/RE3), U$2.1 (IN1)
M3A: PIC32.64 (PMD4/RE4), U$2.2 (IN2)
M3B: PIC32.1 (ETXEN/PMD5/RE5), U$2.3 (IN3)
M3C: PIC32.2 (ETXD0/PMD6/RE6), U$2.4 (IN4)
M3D: PIC32.3 (ETXD1/PMD7/RE7), U$2.5 (IN5)
N1: PIC32.22 (AN9/C2OUT/PMA7/RB9), R10.2
N2: PIC32.23 (TMS/AN10/CVREFOUT/PMA13/RB10), R2.2
unnamed: U2.25 (RX2), U$4.1
unnamed: ANALOG.1, R25.2
unnamed: ANALOG.2, R24.2
unnamed: C3.2, F1.2, U3.5 (OUTB)
unnamed: PIC32.46 (OC1/INT0/RD0), R4.1
unnamed: PIC32.14 (AN2/C2IN-/CN4/RB2), R20.1
unnamed: U2.21 (TX2), U$3.1
unnamed: R18.1, UARTRX4.A
unnamed: ANALOG.3, R23.2
unnamed: PIC32.13 (AN3/C2IN+/CN5/RB3), R23.1
unnamed: C17.1, ECS-240-20-33-TR1.1, PIC32.39 (OSC1/CLKI/RC12)
unnamed: C18.2, ECS-240-20-33-TR1.3, PIC32.40 (OSC2/CLKO/RC15)
unnamed: PIC32.12 (AN4/C1IN-/CN6/RB4), R24.1
unnamed: PIC32.11 (AN5/C1IN+/VBUSON/CN7/RB5), R25.1
unnamed: ANALOG.4, R20.2
unnamed: C16.2, PIC32.19 (AVDD), R1.1
unnamed: C20.2, C21.2, PIC32.56 (VCAP/VDDCORE)
unnamed: Q1.3 (D), R3.2, SERVO1.3
unnamed: PIC32.16 (PGED1/AN0/VREF+/CVREF+/PMA6/CN2/RB0), PIC_PROG1.4
unnamed: LED0.C, R10.1
unnamed: PIC32.8 (~SS2/U6RX/~U3CTS/PMA2/CN11/RG9), TOUCHSCREEN.4, U$3.2
unnamed: LED1.C, R2.1
unnamed: R7.1, S1.3
unnamed: LED3.C, R11.1
unnamed: Q2.3 (D), R22.2, SERVO2.3
unnamed: Q1.1 (G), R5.1
unnamed: Q2.1 (G), R21.1
unnamed: LIDAR.3, PIC32.49 (SCK3/U4TX/U1RTS/OC2/RD1), UARTRX4.C
unnamed: LIDAR.2, PIC32.43 (~SS3/U4RX/~U1CTS/SDA1/IC2/INT2/RD9), UARTTX4.C
unnamed: MOTORA.A, R8.1
unnamed: PIC32.24 (TDO/AN11/PMA12/RB11), R11.2
unnamed: PIC32.17 (PGEC2/AN6/OCFA/RB6), R26.1
unnamed: ANALOG.5, R26.2
unnamed: U2.9 (RX1), U$6.2
unnamed: PIC32.21 (AN8/~SS4/U5RX/~U2CTS/C1OUT/RB8), U$5.1
unnamed: R19.1, UARTTX4.A
unnamed: F4.2, VIN.2
unnamed: JP3.1, U$1.16 (OUT1)
unnamed: JP3.2, U$1.15 (OUT2)
unnamed: JP3.3, U$1.14 (OUT3)
unnamed: JP3.4, U$1.13 (OUT4)
unnamed: JP2.1, U$1.12 (OUT5)
unnamed: JP2.2, U$1.11 (OUT6)
unnamed: JP2.3, U$1.10 (OUT7)
unnamed: JP2.4, U$2.16 (OUT1)
unnamed: JP1.1, U$2.15 (OUT2)
unnamed: JP1.2, U$2.14 (OUT3)
unnamed: JP1.3, U$2.13 (OUT4)
unnamed: JP1.4, U$2.12 (OUT5)
unnamed: U2.5 (TX1), U$5.2
unnamed: I2C2.1, PIC32.50 (SDA3/SDI3/U1RX/OC3/RD2)
unnamed: I2C2.2, PIC32.51 (SCL3/SDO3/U1TX/OC4/RD3)
unnamed: PIC32.29 (AN14/SCK4/U5TX/~U2RTSU2RTS/PMALH/PMA1/R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), U$6.1
unnamed: U2.22 (WLANLED), WLAN.C
unnamed: LED6.C, U2.20 (ELED2)
unnamed: LED7.C, U2.18 (ELED1)
unnamed: LED7.A, R15.1
unnamed: LED6.A, R14.1
unnamed: R6.1, WLAN.A
ONE: LED5.C, R13.1
PICUART_RX: I2C1.1, PIC32.31 (AC1TX/SDA5/SDI4/U2RX/PMA9/CN17/RF4)
PICUART_TX: I2C1.2, PIC32.32 (AC1RX/SCL5/SDO4/U2TX/PMA8/CN18/RF5)
PIC_HANG_CHK: PIC32.15 (PGEC1/AN1/VREF-/CVREF-/CN3/RB1), PIC_PROG1.5
SCK2: PIC32.4 (SCK2A/U3BTX/~U3ARTS/PMA5/CN8/RG6), TOUCHSCREEN.1
SDI2: PIC32.5 (SDA2A/SDI2A/U3ARX/PMA4/CN9/RG7), TOUCHSCREEN.3
SDO2: PIC32.6 (SCL4/SDO2/U3TX/PMA3/CN10/RG8), TOUCHSCREEN.5, U$4.2
SERV1: PIC32.28 (TDI/AN13/PMA10/RB13), Q1.2 (S), R13.2, R16.1
SERV2: PIC32.27 (TCK/AN12/PMA11/RB12), Q2.2 (S), R12.2, R17.1
TWO: LED4.C, R12.1
VCC: C5.A (+), F4.1, U1.1 (CTL), U1.2 (VCC); also elsewhere on the board
VUSB: PIC32.35 (VUSB)

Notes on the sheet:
Reference Schematic From: https://xv11hacking.wikispaces.com/Interfacing+LIDAR+sensor+to+other+Devices
freewheeling diode for DC motor
LIDAR UART4
dual low-side mosfet driver (logic level shifter 25ns) 1.5A max output
For Use with 7" touchscreen: ER-TFTM070-5 link: http://www.buydisplay.com/default/7-inch-lcd-module-capacitive-touch-screen-panel-i2c-spi-serial
add to lantronix

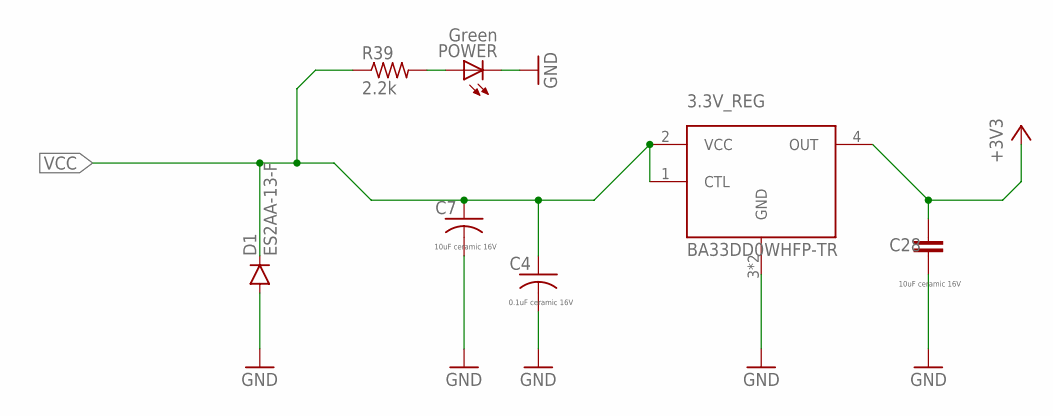
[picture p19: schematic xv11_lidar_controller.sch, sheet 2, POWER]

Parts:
3.3V_REG: BA33DD0WHFP-TR; HRP5
C4: 0.1uF ceramic 16V; C0805K
C7: 10uF ceramic 16V; C0805K
C28: 10uF ceramic 16V; 0805
D1: ES2AA-13-F; SMA-DIODE
POWER: Green; CHIP-LED0805
R39: 2.2k; R0805

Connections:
+3V3: 3.3V_REG.4 (OUT), C28.1; also elsewhere on the board
GND: 3.3V_REG.3 (GND), 3.3V_REG.G (GND), C4.2, C7.2, C28.2, D1.A, POWER.C; also elsewhere on the board
unnamed: POWER.A, R39.2
VCC: 3.3V_REG.1 (CTL), 3.3V_REG.2 (VCC), C4.1, C7.1, D1.C, R39.1; also elsewhere on the board

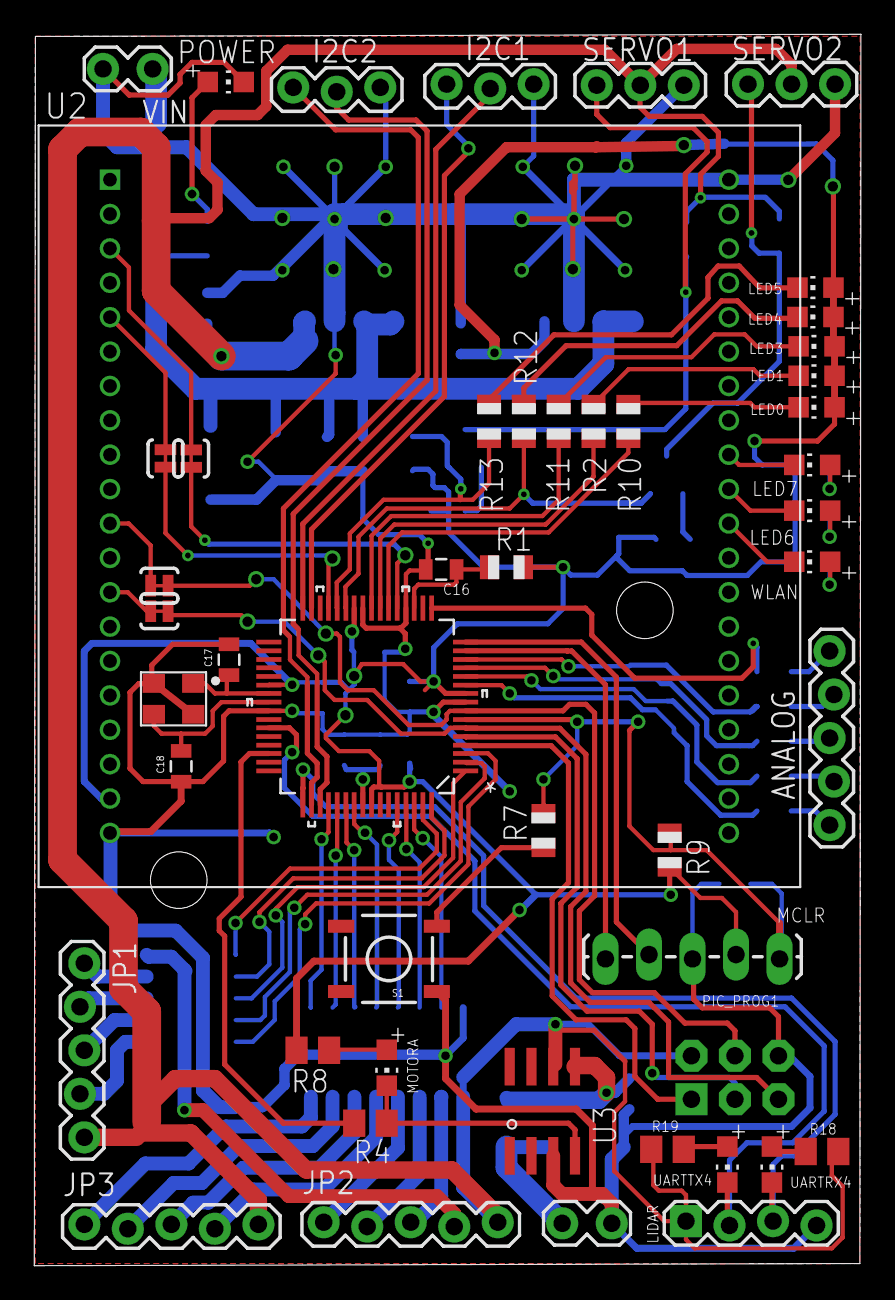
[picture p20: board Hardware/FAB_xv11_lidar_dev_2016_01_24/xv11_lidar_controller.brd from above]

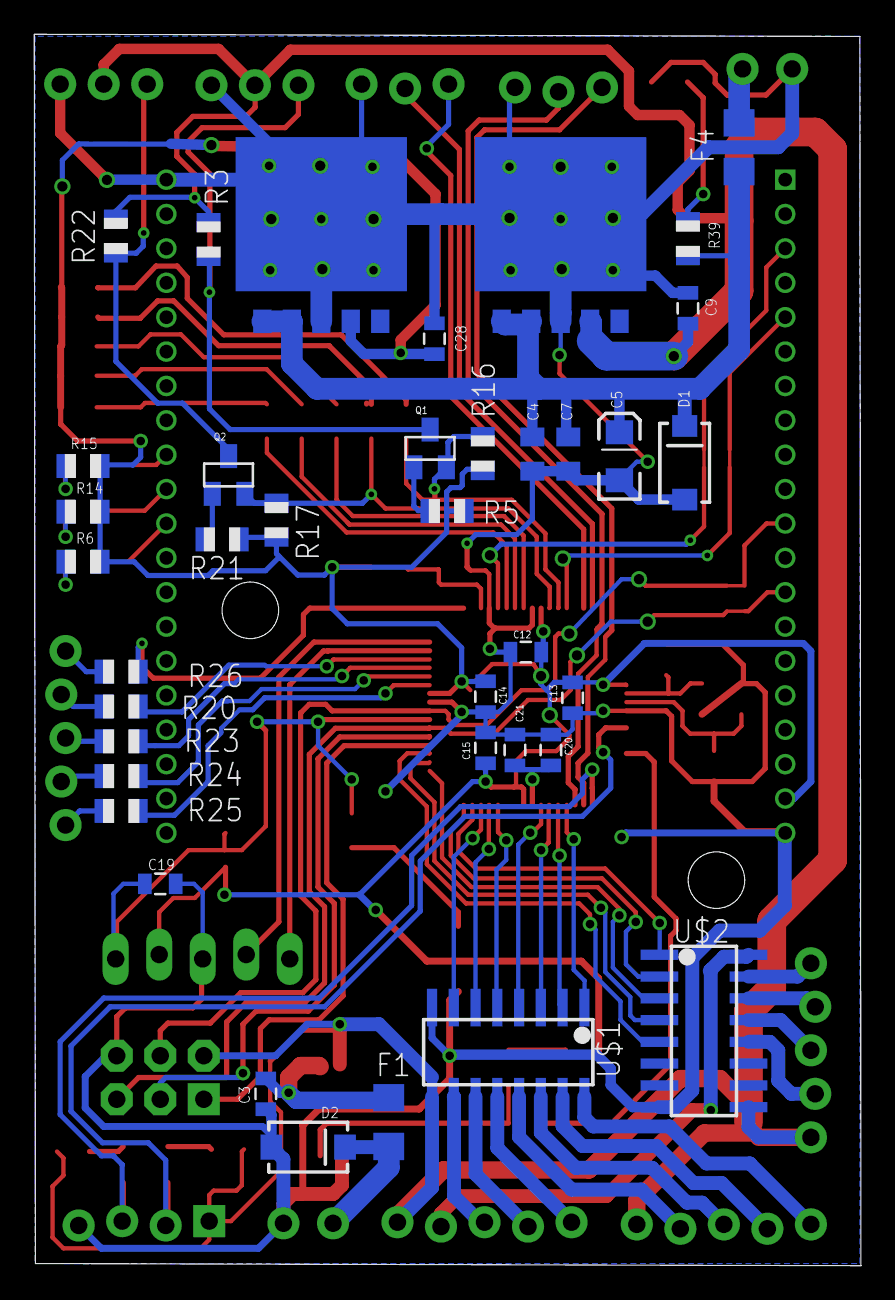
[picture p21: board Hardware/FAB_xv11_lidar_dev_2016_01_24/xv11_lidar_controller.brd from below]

Board: 2 copper layers, 48.2 x 71.9 mm, 89 parts (38 on the bottom side), 91 nets.

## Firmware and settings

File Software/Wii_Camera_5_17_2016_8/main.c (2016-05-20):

#include <xc.h>
#define _SUPPRESS_PLIB_WARNING
#include <plib.h>
#include <stdio.h>
#include <math.h>
#include <stdbool.h>
#include "main.h"
#include "wiiCamera.h"
#include "Servos.h"
#include "SinLookupTable.h"
#include "uart_handler.h"


#define CAMERA1 0
#define CAMERA2 1
#define COLLECTOR_BIN 150 // distance apart the wii cameras are in cm?
#define CAMERA_ADDRESS 3
#define LANTRONIX   4
#define DEGREE_TO_RADIAN  0.0174532925194329577

// DEVCFG3
// USERID = No Setting
#pragma config FSRSSEL = PRIORITY_7     // SRS Select (SRS Priority 7)
#pragma config FCANIO = OFF             // CAN I/O Pin Select (Alternate CAN I/O)
#pragma config FUSBIDIO = OFF           // USB USID Selection (Controlled by Port Function)
#pragma config FVBUSONIO = OFF          // USB VBUS ON Selection (Controlled by Port Function)

// DEVCFG2
#pragma config FPLLIDIV = DIV_6         // PLL Input Divider (6x Divider) (Phase Lock Loop- stepping up the frequency)
#pragma config FPLLMUL = MUL_20         // PLL Multiplier (20x Multiplier)
#pragma config UPLLIDIV = DIV_6         // USB PLL Input Divider (6x Divider)
#pragma config UPLLEN = ON              // USB PLL Enable (Enabled)
#pragma config FPLLODIV = DIV_1         // System PLL Output Clock Divider (PLL Divide by 1)

// DEVCFG1
#pragma config FNOSC = PRIPLL           // Oscillator Selection Bits (Primary Osc w/PLL (XT+,HS+,EC+PLL))
#pragma config FSOSCEN = OFF            // Secondary Oscillator Enable (Disabled)
#pragma config IESO = OFF               // Internal/External Switch Over (Disabled)
#pragma config POSCMOD = HS             // Primary Oscillator Configuration (HS osc mode)
#pragma config OSCIOFNC = OFF           // CLKO Output Signal Active on the OSCO Pin (Disabled)
#pragma config FPBDIV = DIV_1           // Peripheral Clock Divisor (Pb_Clk is Sys_Clk/1)
#pragma config FCKSM = CSDCMD           // Clock Switching and Monitor Selection (Clock Switch Disable, FSCM Disabled)
#pragma config WDTPS = PS1048576        // Watchdog Timer Postscaler (1:1048576)
#pragma config FWDTEN = OFF             // Watchdog Timer Enable (WDT Disabled (SWDTEN Bit Controls))

// DEVCFG0
#pragma config DEBUG = ON               // Background Debugger Enable (Debugger is enabled)
#pragma config ICESEL = ICS_PGx1        // ICE/ICD Comm Channel Select (ICE EMUC1/EMUD1 pins shared with PGC1/PGD1)
#pragma config PWP = OFF                // Program Flash Write Protect (Disable)
#pragma config BWP = OFF                // Boot Flash Write Protect bit (Protection Disabled)
#pragma config CP = OFF                 // Code Protect (Protection Disabled)

#define SYS_FREQ 80000000 // system frequency

bool awaitingData = false;
bool dataAvailable = false;

int receiveArray[20];

void timers(void){
    // timer for servo 1
    T4CONbits.ON = 0;
    T4CONbits.TCKPS = 0b101; // 32 prescalar
    T4CONbits.TGATE = 0;
    T4CONbits.T32 = 0;
    IFS0CLR = _IFS0_T4IF_MASK;
    IEC0SET = _IEC0_T4IE_MASK;
    IPC4SET = ((0x111 << _IPC4_T4IP_POSITION) | (0x1 << _IPC4_T4IS_POSITION));
    T4CONbits.ON = 1;

    //timer for servo 2
    T5CONbits.ON = 0;
    T5CONbits.TCKPS = 0b101; // 32 prescalar
    T5CONbits.TGATE = 0;
    IFS0CLR = _IFS0_T5IF_MASK;
    IEC0SET = _IEC0_T5IE_MASK;
    IPC5SET = ((0x111 << _IPC5_T5IP_POSITION) | (0x1 << _IPC5_T5IS_POSITION)); // What does this do?

    T5CONbits.ON = 1;

    // general timing timer for everything
    T3CONbits.ON = 0;
    T3CONbits.TCKPS = 0b111; //256 prescalar
    T3CONbits.TGATE = 0;
    //TPB_clock is the clock resource for peripherals on pic32MX (p.201) (look at system clock / "FPBDIV") - located in configuration bits
    //Example:
    //Desired_Period == 100ms
    //PR# = Desired_Period / [(1/Fosc)*Prescaler]
    //PR# = 0.100seconds / [(1/80MHz)*256] = 31250
    PR3 = 31250;
    IFS0CLR = _IFS0_T3IF_MASK;
    IEC0SET = _IEC0_T3IE_MASK;
    IPC3SET = ((0x1 << _IPC3_T3IP_POSITION) | (0x1 << _IPC3_T3IS_POSITION));
    T3CONbits.ON = 1;


}
void initializeBits(void)
{
     SYSTEMConfig(SYS_FREQ, SYS_CFG_ALL); //memory management
    //INTEnableSystemMultiVectoredInt(); //enables interrupts

    DDPCONbits.JTAGEN = 0; // This turns off the JTAG and allows PORTA pins to be used (Must disable the JTAG module in order to use LAT registers to set discrete outputs (LEDs)

    // TRIS ? Set a pin as Input or Output
    // LAT ? output
    // PORT ? inpput
    //LED
    TRISBbits.TRISB9 = 0;
    TRISBbits.TRISB10 = 0;
    TRISBbits.TRISB11 = 0;
    TRISBbits.TRISB12 = 0;
    TRISBbits.TRISB13 = 0;

    LATBbits.LATB9 = 1;
    LATBbits.LATB10 = 1;
    LATBbits.LATB11 = 1;
    LATBbits.LATB12 = 1;
    LATBbits.LATB13 = 1;

    I2C3BRG = 390;
    IPC6bits.I2C3IP = 1; //priority 1
    IPC6bits.SPI1AIS = 2; //priority 2
    IEC0bits.I2C3MIE = 1; //enable I2C interrupt
    I2C3CONbits.ON = 1; //enable I2C

    I2C5BRG = 390;
    IPC8bits.I2C5IP = 1; //priority 1
    IPC8bits.SPI3AIS = 2; //priority 2
    IEC1bits.I2C5MIE = 1; //enable I2C interrupt
    I2C5CONbits.ON = 1; //enable I2C

   
    UART();
    begin(&receiveArray, sizeof(receiveArray),CAMERA_ADDRESS,false, Send_put,Receive_get,Receive_available,Receive_peek);
    
    timers();

    INTEnableSystemMultiVectoredInt(); //enables interrupts

    INTEnableInterrupts(); // enable interrupts
}

int CalculateHeight(unsigned char state)
{
    // if don't see both blobs
    if(state < 6)
        return 0;
    // if see both blobs (either one each for the servos, or both servos see both)
    return COLLECTOR_BIN * sin(getAngle1()*DEGREE_TO_RADIAN)*sin(getAngle2()*DEGREE_TO_RADIAN)/sin((180-getAngle1()-getAngle2())*DEGREE_TO_RADIAN);
}
int offCenter(unsigned char state)
{
    // if don't see both blobs
    if(state < 6)
        return 0;
    // if see both blobs (either one each for the servos, or both servos see both)
    return COLLECTOR_BIN/2 - COLLECTOR_BIN*sin(getAngle2()*DEGREE_TO_RADIAN)*cos(getAngle1()*DEGREE_TO_RADIAN)/ sin((180-getAngle1()- getAngle2())*DEGREE_TO_RADIAN);
}

unsigned char determineState()
{
    bool goodr1 = false;
    bool goodr2 = false;
    if(result1<1023)
    {
        goodr1 = true;
    }
    if(result2<1023)
    {
        goodr2 = true;
    }
    if(goodr1 && goodr2){ // good r values from the blobs
    if(getBlobsSeen(CAMERA1)<=0 && getBlobsSeen(CAMERA2)<=0)// can't see any blobs
        return 0;
    if((getBlobsSeen(CAMERA1)>1 && getBlobsSeen(CAMERA2)>1))// both see both blobs
        return 7;
    if(getBlobsSeen(CAMERA1)==1 && getBlobsSeen(CAMERA2)<=0)//camera1 sees one blob only
        return 1;
    if(getBlobsSeen(CAMERA1)<=0 && getBlobsSeen(CAMERA2)==1) // camera2 sees one blob only
        return 2;
    if(getBlobsSeen(CAMERA1)>1 && getBlobsSeen(CAMERA2)<=0) // camera1 sees both blobs only
        return 3;
    if(getBlobsSeen(CAMERA1)<=0 && getBlobsSeen(CAMERA2)>1) // camera2 sees both blobs only
       return 4;
    if(getBlobsSeen(CAMERA1)==1 && getBlobsSeen(CAMERA2)==1) // both cameras see one blob
    {
        if((180-getAngle1()-getAngle2())<0) //cameras each see different blobs
            return 5;
     return 6; // cameras see same blob
    }
    }
    else if(goodr1&&!goodr2) // no good blobs from camera2
    {
      if(getBlobsSeen(CAMERA1)<=0)// can't see any blobs camera1
        return 0;
      if(getBlobsSeen(CAMERA1)==1)//camera1 sees one blob only
        return 1;
      if(getBlobsSeen(CAMERA1)>1) // camera1 sees both blobs only
        return 3;
    }
    else if (!goodr1&& goodr2)// no good blobs from camera1
    {
      if(getBlobsSeen(CAMERA2)<=0)// can't see any blobs camera2
        return 0;
      if(getBlobsSeen(CAMERA2)==1) // camera2 sees one blob only
        return 2;
      if(getBlobsSeen(CAMERA2)>1) // camera2 sees both blobs only
       return 4;
    }
    else
    {
        return 0;
    }

}

void main(void) {
   
    initializeBits();
    while(wiiInitStep<=5){

    initializeWii();
  
    }
//timers();
        //delay
    int i = 0;
    while (i < 100000) {

        i++;
    }

       
    while (1) {

    
        if (ms200done && !awaitingData) {//Do I need to wait until not dataAvailable as well?

        //U6TXREG=0x99;
        unsigned char state = determineState();
        ToSend(0,CAMERA_ADDRESS);
        ToSend(9,state);
        ToSend(10,getAngle1());//left camera when facing, lidar side
        ToSend(11,getAngle2());//right camera
        ToSend(12,offCenter(state));
        ToSend(13,CalculateHeight(state));
        ToSend(14,getDifferenceX(CAMERA1));//left camera, lidar side
        ToSend(15,getDifferenceX(CAMERA2)); // right camera
     
        sendData(LANTRONIX);


            LATBbits.LATB11 ^= 1;
            read(CAMERA1);
            read(CAMERA2);
            ms200done = false;
            awaitingData = true;
        }
         if (awaitingData) {
            if (StatusI2Cone() == 1 && StatusI2Ctwo()==1) {
                dataAvailable = true;
                awaitingData = false;
            }
            else if(StatusI2Cone() == 2 || StatusI2Ctwo()==2)
            {
                awaitingData=false;
            }
        }
        if (dataAvailable) {

            dataAvailable = false;
            Sort(CAMERA1);
            Sort(CAMERA2);
            result1 = PickBeacon(CAMERA1);
            result2 = PickBeacon(CAMERA2);
            //camera and servo1
            //seekBeacon(CAMERA1, result1);
            //seekBeacon(CAMERA2, result2);
            //printf("Hi");
//            if (getBlobsSeen(CAMERA1) > 0 && result1 < 1023) {
//                determineAngle(true, result1, CAMERA1);
//            } else {
//                determineAngle(false, result1, CAMERA1);
//
//            }
//            // camera and servo 2
//            if (getBlobsSeen(CAMERA2) > 0 && result2 <= 1023) {
//                determineAngle(true, result2, CAMERA2);
//            } else {
//                determineAngle(false, result2, CAMERA2);
//            }
//            static int counter =0;
//            if( counter>2)
//            {
            seekBeacon(CAMERA1, result1);
            seekBeacon(CAMERA2, result2);
//                counter = 0;
//            }
//            counter++;
        }

     



         }
    
}

static enum {
    EXCEP_IRQ = 0, // interrupt
    EXCEP_AdEL = 4, // address error exception (load or ifetch)
    EXCEP_AdES, // address error exception (store)
    EXCEP_IBE, // bus error (ifetch)
    EXCEP_DBE, // bus error (load/store)
    EXCEP_Sys, // syscall
    EXCEP_Bp, // breakpoint
    EXCEP_RI, // reserved instruction
    EXCEP_CpU, // coprocessor unusable
    EXCEP_Overflow, // arithmetic overflow
    EXCEP_Trap, // trap (possible divide by zero)
    EXCEP_IS1 = 16, // implementation specfic 1
    EXCEP_CEU, // CorExtend Unuseable
    EXCEP_C2E // coprocessor 2
} _excep_code;
static unsigned int _epc_code;
static unsigned int _excep_addr;
// this function overrides the normal _weak_ generic handler

void _general_exception_handler(void) {
    asm volatile("mfc0 %0,$13" : "=r" (_excep_code));
    asm volatile("mfc0 %0,$14" : "=r" (_excep_addr));
    _excep_code = (_excep_code & 0x0000007C) >> 2;
    LATBbits.LATB10 = 0; //test 1
    while (1) {

        // Examine _excep_code to identify the type of exception
        // Examine _excep_addr to find the address that caused the exception
    }
}

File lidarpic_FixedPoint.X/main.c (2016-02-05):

 /* File:   main.c
 * Author: Igor
 * Created on July 3, 2015, 1:11 PM
 */
#include <xc.h>
#include <stdbool.h>
#include <stdio.h>
#include "main.h"
#include <math.h>
#include <string.h>


// PIC32MX575F512H Configuration Bit Settings

// 'C' source line config statements

// DEVCFG3
// USERID = No Setting
#pragma config FSRSSEL = PRIORITY_7     // SRS Select (SRS Priority 7)
#pragma config FCANIO = OFF             // CAN I/O Pin Select (Alternate CAN I/O)
#pragma config FUSBIDIO = OFF           // USB USID Selection (Controlled by Port Function)
#pragma config FVBUSONIO = OFF          // USB VBUS ON Selection (Controlled by Port Function)

// DEVCFG2
#pragma config FPLLIDIV = DIV_6         // PLL Input Divider (6x Divider)
#pragma config FPLLMUL = MUL_20         // PLL Multiplier (20x Multiplier)
#pragma config UPLLIDIV = DIV_6         // USB PLL Input Divider (6x Divider)
#pragma config UPLLEN = ON              // USB PLL Enable (Enabled)
#pragma config FPLLODIV = DIV_1         // System PLL Output Clock Divider (PLL Divide by 1)

// DEVCFG1
#pragma config FNOSC = PRIPLL           // Oscillator Selection Bits (Primary Osc w/PLL (XT+,HS+,EC+PLL))
#pragma config FSOSCEN = OFF            // Secondary Oscillator Enable (Disabled)
#pragma config IESO = OFF               // Internal/External Switch Over (Disabled)
#pragma config POSCMOD = HS             // Primary Oscillator Configuration (HS osc mode)
#pragma config OSCIOFNC = OFF           // CLKO Output Signal Active on the OSCO Pin (Disabled)
#pragma config FPBDIV = DIV_1           // Peripheral Clock Divisor (Pb_Clk is Sys_Clk/1)
#pragma config FCKSM = CSDCMD           // Clock Switching and Monitor Selection (Clock Switch Disable, FSCM Disabled)
#pragma config WDTPS = PS1048576        // Watchdog Timer Postscaler (1:1048576)
#pragma config FWDTEN = OFF             // Watchdog Timer Enable (WDT Disabled (SWDTEN Bit Controls))

// DEVCFG0
#pragma config DEBUG = ON               // Background Debugger Enable (Debugger is enabled)
#pragma config ICESEL = ICS_PGx1        // ICE/ICD Comm Channel Select (ICE EMUC1/EMUD1 pins shared with PGC1/PGD1)
#pragma config PWP = OFF                // Program Flash Write Protect (Disable)
#pragma config BWP = OFF                // Boot Flash Write Protect bit (Protection Disabled)
#pragma config CP = OFF                 // Code Protect (Protection Disabled)


void delay(void){
    for(v=0; v<60000; v++);
}

//  LCD Stuff:
//void DrawDistanceMap(void) {
//	// UP TO 3500 i distance = 3.5m
//    short deg;
//    static short LCDDisplayX[360], LCDDisplayY[360];
//    for (deg = 0; deg < 360; deg++) {
//        LCD_SetTextColor(LCD_COLOR_BLACK);
//        LCD_DrawLine(x[deg], y[deg], 1, LCD_DIR_HORIZONTAL); // PutPixel(x, y);
//        LCD_DrawLine(x[deg]+1, y[deg], 1, LCD_DIR_HORIZONTAL); // PutPixel(x, y);
//        LCD_DrawLine(x[deg], y[deg]+1, 1, LCD_DIR_HORIZONTAL); // PutPixel(x, y);
//        LCD_DrawLine(x[deg]+1, y[deg]+1, 1, LCD_DIR_HORIZONTAL); // PutPixel(x, y);
//
//        if((Distance[deg] < 3000) && (Distance[deg] > 0)) {
////            displayDistance = Distance[deg] / 25.0f;
////            x[deg] = (cos(M_PI_2-radians) * displayDistance) + 120;
////            y[deg] = (sin(M_PI_2-radians) * displayDistance) + 120;
//            LCD_SetTextColor(LCD_COLOR_WHITE);
//            LCDDisplayX = (XCoordMeters[deg] >> LCD_SCALING) + 120;
//            LCDDisplayY = (YCoordMeters[deg] >> LCD_SCALING) + 120;
//
//            LCD_DrawLine(x[deg], y[deg], 1, LCD_DIR_HORIZONTAL); // PutPixel(x, y);
//            LCD_DrawLine(x[deg]+1, y[deg], 1, LCD_DIR_HORIZONTAL); // PutPixel(x, y);
//            LCD_DrawLine(x[deg], y[deg]+1, 1, LCD_DIR_HORIZONTAL); // PutPixel(x, y);
//            LCD_DrawLine(x[deg]+1, y[deg]+1, 1, LCD_DIR_HORIZONTAL); // PutPixel(x, y);
//        }
//    }
//    LCD_SetTextColor(LCD_COLOR_BLUE2);
//    LCD_DrawFullCircle(120, 120, 6);
//}


int AllMeasurementsTaken(void){
    int j = 0;
    for(j=0;j<90;j++) {
        LIDARdecode();
    }
    //Verify that all 360 degrees have a distance measurement
    for(i=0;i<360;i++) {
        AnglesCoveredTotal += SuccessfulMeasurements[i];
    }
    if(AnglesCoveredTotal >=359) { // all angles have data in them
        return 1;
    }else { //not all angles have distance data in them
        AnglesCoveredTotal = 0;
        return 0;
    }
    return 0;
}


void main(void){
    TRISEbits.TRISE4 = 0;
    TRISEbits.TRISE3 = 0;
    LATEbits.LATE3 = 1;
    initialize();
    printf("\r\nPIC_RST\r\n");
    short j = 0;
    short DistanceDifferences[360];
    short startOfDetectedObject = 0;
    short endOfDetectedObject = 0;

    //Initialize all distances to '1' so I can see which ones are not getting written to
    for(i=0;i<360;i++) {
        Distance[i] = 1;
    }

    while (1){
////////        if (AllMeasurementsTaken() == 1) {
        if(LIDARdecode()==1) {
            LATEbits.LATE4 ^= 0; //Toggle LED1 on,off,on,off

            if(AnglesCoveredTotal >= 180) {
                //Show first index as zero
                printf("ChkPass \r\n",0);
                IEC0bits.U1TXIE = 1; // enable TX1 interrupt so the pic starts sending debug data

                if(operationMode==TESTMODE) {
                    U5STAbits.URXEN = 0; // disable uart receive (Do not allow Receive Data from Lidar UART5)
                    U5MODEbits.ON = 0; // disable whole uart5 module
                    printf("\x1b[HDisplayPolarData\r\n"); // ANSI Terminal code: (ESC[H == home) & (ESC[2J == clear screen)
                    for(i=0;i<360;i++) {
                        if(U1STAbits.UTXBF == 0) { //check to see if the UART buffer is not full - if it is not full, send debug data out UART1
                            if ((i % 16) == 0) { //print 16 distances per line
                                printf("\r\n%4u: ",i); //print 16 distances per line '\r\n' causes prompt to carraige return
                            }
                            printf("%4u ",Distance[i]); //Print out the data to 4, 16-bit unsigned integer digits
                        } else {
                            i--; //keep index at same value if the UART1 TX debug buffer is full
                        }
//                        printf("\x1b[0J"); // ANSI Terminal code: (ESC[2J == clear screen below cursor)
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

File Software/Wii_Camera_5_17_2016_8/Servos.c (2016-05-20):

#include <xc.h>
#include <sys/attribs.h>
#include "Servos.h"

unsigned char angle [2] = {0, 0};
bool clockwise[] = {true, true};
bool beaconExists[2] = {false, false};
bool beaconCentered[2] = {false, false};
unsigned short anglex1 = 2500;
unsigned short anglex2 = 2500; //2.1ms 180degrees, 1.5 90degrees, 955 0degrees
bool setHigh1 = false;
bool setHigh2 = false;

int isAbout(int compareThis, int toThis, int range) {
    return ((compareThis > toThis - range) && (compareThis < toThis + range));
}
void seekBeacon(int cameraNumber, int result) {
    if (result >= INVALID || result <=0) {
        beaconExists[cameraNumber] = false;
        beaconCentered[cameraNumber] = false;
        //SWEEP
        if ((angle[cameraNumber] < (SERVO_MAX - SERVO_STEP_WIDE)) && clockwise[cameraNumber]) {
            angle[cameraNumber] += SERVO_STEP_WIDE;
//            if (cameraNumber == LEFT_CAMERA) setAngle1(angleSet[cameraNumber]);
//            else setAngle2(angleSet[cameraNumber]);
        } else if (clockwise[cameraNumber]) {
            clockwise[cameraNumber] = false;
//            numberSweeps[cameraNumber]++;
        }
        if ((angle[cameraNumber] > (SERVO_MIN + SERVO_STEP_WIDE)) && !clockwise[cameraNumber]) {
            angle[cameraNumber] -= SERVO_STEP_WIDE;
//            if (cameraNumber == LEFT_CAMERA) setAngle1(angleSet[cameraNumber]);
//            else setAngle2(angleSet[cameraNumber]);
        } else if (!clockwise[cameraNumber]) {
            clockwise[cameraNumber] = true;
//            numberSweeps[cameraNumber]++;
        }
    } else {
        int increment;
        
            if (!isAbout(result, MIDDLE_X, BUFFER_X)) {
                beaconExists[cameraNumber] = 1;
                beaconCentered[cameraNumber] = 0;
                if (result> MIDDLE_X) {
                    increment = ((result - MIDDLE_X)) / 20;
                    if (angle[cameraNumber] > (SERVO_MIN + increment)) {
                        angle[cameraNumber] -= increment;
//                        setAngle1(angleSet[cameraNumber]);
                    }
                } else {
                    increment = ((MIDDLE_X - result)) / 20;
                    if (angle[cameraNumber] < (SERVO_MAX - increment)) {
                        angle[cameraNumber] += increment;
//                        setAngle1(angleSet[cameraNumber]);
                    }
                }
            } else {
                beaconExists[cameraNumber] = 1;
//                beaconAngle[cameraNumber] = angleSet[cameraNumber];
                beaconCentered[cameraNumber] = 1;
            }
       
    }
}
//void determineAngle(bool haveBlob, short blobX, unsigned char servo) {
////    if (!haveBlob) {
////        if ((angle[servo] < 180) && clockwise[servo]) {// going to the right until end point of travel reached
////            angle[servo] += SERVO_WIDE_STEP;
////        } else if ((angle[servo] > (SERVO_WIDE_STEP + 1)) && !clockwise[servo]) {// going to the left
////            angle[servo] -= SERVO_WIDE_STEP;
////        }
////        if ((angle[servo] >= 180) || (angle[servo] <= SERVO_WIDE_STEP)) {
////
////            if (angle[servo] >= 180) {
////                angle[servo] = 179;
////                clockwise[servo] = false;
////            } else {
////                angle[servo] = 1;
////                clockwise[servo] = true;
////            }
////
////        }
////        beaconExists[servo] = false;
////    } else if (!beaconExists[servo]) {
////        if (blobX < MIN_CENTER_LIMIT)// blob is to the left of the center
////        {
////            if ((MIDDLE_X - blobX) < BUFFER_X)// go to the right small step
////                angle[servo]++;
////            else
////                angle[servo] += SERVO_MED_STEP;
////            clockwise[servo] = true;
////        } else if (blobX > MAX_CENTER_LIMIT) {// blob is to the right of the center, go left
////            if ((blobX - MIDDLE_X) < BUFFER_X) // go to the right small step
////                angle[servo]--;
////            else
////                angle[servo] -= SERVO_MED_STEP;
////            clockwise[servo] = false;
////        } else // blobX is in the middleish
////        {
////            beaconExists[servo] = true;
////        }
////
////        if ((angle[servo] >= 180) || (angle[servo] < SERVO_MED_STEP)) {
////
////            if (angle[servo] >= 180) {
////                angle[servo] = 179;
////                clockwise[servo] = false;
////            } else {
////                angle[servo] = 1;
////                clockwise[servo] = true;
////            }
////
////        }
////    }
//          if (!haveBlob) {
//                if (angle[servo] < 180 && clockwise[servo]) {// going to the right until end point of travel reached
//                    angle[servo]+=15;
//                } else if (angle[servo] > 15 && !clockwise[servo]) {// going to the left
//                    angle[servo]-=15;
//                }
//                beaconExists[servo]= false;
//            }
//          else if (!beaconExists[servo]) {
//           if (blobX < (MIDDLE_X - BUFFER_X))// blob is to the left of the center
//            {
//                // go to the right
//                angle[servo]++;
//                clockwise[servo] = true;
//            } else if (blobX > (MIDDLE_X + BUFFER_X)) {// blob is to the right of the center, go left
//                angle[servo]--;
//                clockwise[servo] = false;
//            } else // blobX is in the middle
//            {
//                beaconExists[servo] = true;
//            }
//        }
//        if (angle[servo] >= 180 || angle[servo] <= 15) {
//
//            if (angle[servo] >= 180) {
//                angle[servo] = 179;
//                clockwise[servo] = false;
//            } else{
//                angle[servo] = 1;
//                clockwise[servo] = true;
//            }
//        }
//
//}

void setAngle1(short d) {
    if (d < 180 && d > 0) {
        anglex1 = d * DEGREE + 2500;
    } else if (d >= 180) {
        anglex1 = DEGREE180;
    } else
        anglex1 = DEGREE0;
}

void setAngle2(short d) {
    if (d <= 180 && d >= 0) {
        anglex2 = d * DEGREE + 2500;
    } else if (d > 180) {
        anglex1 = DEGREE180;
    } else
        anglex1 = DEGREE0;
}

unsigned char getAngle1(void)// internal angle of the servo1
{
    return ((anglex1 - 2500) / DEGREE);
}

unsigned char getAngle2(void) // internal angle of the servo2
{
    return(180- ((anglex2 - 2500) / DEGREE));
}


//where does th 80000000 come from?// clock of the processor 80 MHz
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

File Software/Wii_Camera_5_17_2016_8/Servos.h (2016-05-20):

/* 
 * File:   Servos.h
 * Author: Dana
 *
 * Created on May 12, 2016, 7:54 PM
 */
#include <stdbool.h>



#ifndef SERVOS_H
#define	SERVOS_H

#ifdef	__cplusplus
extern "C" {
#endif
#define MIDDLE_X    511
#define BUFFER_X    100
#define DEGREE      13.8888888888888889
#define DEGREE180   4986 // 5000- buffer of 14
#define DEGREE0     2514 // 2500+ buffer of 14
#define SERVO1 0
#define SERVO2 1
#define SERVO_STEP_WIDE 15
#define SERVO_MAX 180
#define SERVO_MIN 0
#define INVALID 1023


extern unsigned char angle[2]; // 0 degrees to start for pwm
extern unsigned short anglex1;
extern unsigned short anglex2;
extern bool clockwise[2]; //false = left, true = right
extern bool beaconExists[2] ;
extern bool setHigh1;
extern bool setHigh2;

//extern void determineAngle(bool haveBlob, short blobX, unsigned char servo);
extern int isAbout(int compareThis, int toThis, int range);
extern void seekBeacon(int cameraNumber, int result);
extern unsigned char getAngle1(void);
extern unsigned char getAngle2(void);
extern void setAngle1(short d);
extern void setAngle2(short d);

#ifdef	__cplusplus
}
#endif

#endif	/* SERVOS_H */

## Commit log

2016-01-31 First Commit
    Checksum rejecting not letting data populate Distance[360] array
    [Arduino_MEGA_2560-Rev3.brd, Arduino_MEGA_2560-Rev3.sch, ECEparts request -LIDAR.xlsx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]
2016-02-01 Active Polar Readout Added
    Added Faster Printout over UART (Putchar function delay reduced for U1TX
    debugging to PC)
    Hope to test cartesian distances and test for real
    NEED TO MAKE PRINTOUT REFRESH FASTER!!!
2016-02-13 BrokenNewCopy_2016_02_12_Friday
    BrokenUARTVersion(Friday2016_02_12)
    [Arduino_MEGA_2560-Rev3.brd, Arduino_MEGA_2560-Rev3.sch, ECEparts request -LIDAR.xlsx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]
2016-02-13 SuccessfulWorkingCopy
    Works quickly (populates polar data in 40 seconds), but using delayed
    putchar() function in uart_handler.c
    **FOR FUTURE: NEED TO USE INTERRUPTS WITH THE UART U1TX
    NOW WORKS WITH 230400 BAUDRATE FOR U1TX TO TERMINAL
2016-03-19 NOT_WORKING_2016_03_19
    Starting to Add DMA stuff
    [Arduino_MEGA_2560-Rev3.brd, Arduino_MEGA_2560-Rev3.sch]
2016-03-20 TestCodeForTomorrow
    Actually started the DMA (I did not call it in initialize.c before now
    from initialize function)
2016-03-20 Working DMA!!!!
    Need to format the data to show up in terminal better
2016-03-23 Trying to get DMA to print out data better
    data only prints 1 row and repeats (probably something with the DMA
    layers
2016-04-17 NEW_BOARD_NOT_WORKING
    LidarIn: from U5RX to U4RX
    DebugOut: from U1TX to U6TX
2016-04-30 WorkingCodeNEW_BOARD
    need to fix dma output
    [xv11_lidar_controller.brd, xv11_lidar_controller.sch]
2016-05-05 DMA almost working_extra zeros between data elements
    blah
2016-05-08 Motor Speed and Quality Checks for Data
    Quality Check array added to check reflectance of light coming back from
    objects.
    DEBUG THE QUALITY COMING BACK
    Also - changed motor speed to 230RPM
    [ECEparts request -LIDAR.xlsx, ECEpartsrequest pic dev board july 12 2014.xls, PIC32 dev board.brd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]
2016-05-08 Working Modular Code
    Not the user can decide if the parsed data should be printed or not.
2016-05-13 NOT_WORKING_CODE
    Added object detection logic
    indexed lidar offset by 90 degrees
    trying to use blinking LEDs and timers for dubugging
2016-05-14 Debug_Code_ok
    need to test without printing data out
2016-05-14 troubleshooting timers and object detection
2016-05-14 object_detection_using_struct_array
    object detection with struct
    cleaned up folder with excess stuff
    [ECEparts request -LIDAR.xlsx, ECEpartsrequest pic dev board july 12 2014.xls, PIC32 dev board.brd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]
2016-05-15 fixed timer issue_working_in_debug_mode
2016-05-15 WORKING_CODE_MustTestObjectDetectionForAccuracy
    Changed DMA times
    added debugging to showobjects
    **not checking for objects that are close to each other (commented out
    the checking of duplicate objects close to each other)**
    [PIC32 dev board.brd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]
2016-05-16 ERROR_Return_False_Line122_lidar_decoder.c
    Do not know why rejecting the angles behind the lidar prevents objects
    from being detected...
    [lidar_decoder.c]
2016-05-17 troubleshooting
    counter fix
    array length fix
    [lidar_decoder.c]
2016-05-19 RebuildingCode_NotUsingDMA_UARTonly
    must send object information to host
    [TrigLookupTable.xlsx]
2016-05-19 Fixing Sin Lookup Table2
    [lidar_decoder.c]
2016-05-19 not working fixed point
    [lidar_decoder.c, main.c]
2016-05-20 debug_need to filter degree zero
2016-05-20 WORKING_CODE_DetectionOfObjects
    Need to filter objects
    1) prevent duplicate objects from future detections
    2) possibly track moving objects
2016-06-04 WORKING_ObjectTracking
    Added sendRobotLocation() function
    this will be used to send info to navigation processor on the robot.
    **Need to print objects out using a timer to debug the project easier**
2016-06-04 ADDED DOCUMENTATION
    AddedPictureOfDataRecordedForObject
    Corrected FloatingPointMath in Object Detection
    [lidar_decoder.c, main.c]
2016-06-08 UNTESTED_VeclocityVectorAndBearingTrackingOfRobotWhileRobotMoves
    Velocity calculation
    Compass directections (general directed approximation added -->
    North,South,East,West,NE,NW,SE,SW)
    using quality to check how reflective the robot is -->
    if(quality>thresh), found robot!!!!!!!
    Arena perimeter limits were added after looking at included
    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
2016-06-09 VelocityAndBearingRobotObjectCalcsAreIncorrect
    *Need to fix velocity calculations
    1)Tuned quality of object that it must be within to count as object
    2)Added Law of Cosines to calculate the diameter of the object
    3) object must have moved "objectMovedThreshold" in either the x or y
    direction since the last reading
2016-06-11 Fixed Bearing and Velocity calculations in Objectracking.c
    Velocity was changed to subtract last and present x,y terms
    Also bearing calculation was converted from radians to degrees.
2016-06-18 Added Readme.md file for documentation
    [ECEpartsrequest pic dev board july 12 2014.xls, PIC32 dev board.brd, PIC32 dev board.sch]

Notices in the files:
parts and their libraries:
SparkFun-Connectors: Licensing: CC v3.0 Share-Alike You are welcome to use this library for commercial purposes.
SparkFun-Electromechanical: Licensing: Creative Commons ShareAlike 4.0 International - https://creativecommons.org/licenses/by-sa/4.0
